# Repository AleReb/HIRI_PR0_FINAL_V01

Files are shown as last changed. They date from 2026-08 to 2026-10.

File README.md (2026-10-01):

# FirmwarePro (HIRI)

Firmware para estación de monitoreo técnico-científico basada en ESP32, con adquisición de sensores, GNSS, registro en SD, telemetría HTTP y gestor de archivos por WiFi AP.

## Estado

- Plataforma objetivo: **ESP32 Dev Module** (`esp32:esp32:esp32`)
- Versión de referencia documentada: **Pro V0.1.8**

## Funcionalidades principales

- Lectura de **PMS5003** (PM1/PM2.5/PM10 + T/H según modelo)
- Lectura de **SDS198** (PM100)
- Lectura opcional de **SHT31**
- GNSS por módem SIM7600 (posición, altitud, velocidad, satélites, HDOP)
- Registro en **CSV diario** en tarjeta SD
- Envío HTTP de mediciones a backend
- UI local con OLED + 2 botones
- Modo **WiFi SD** con web manager (upload/download/rename/delete)
- Captive portal DNS para mejor compatibilidad en Windows

## Carrusel de datos persistente

En **Opciones > Configuración > Carrusel**, BTN2 abre una pantalla de control
similar a RTC. Allí **BTN2 activa/desactiva** el carrusel y **BTN1 sale**.
El estado ON/OFF se guarda en flash y se conserva al apagar o reiniciar.
Por defecto está desactivado.

Desde Serial (115200 baud, nueva línea):

```text
set carousel on
set carousel off
config display
```

Los comandos `set` guardan automáticamente con el mismo `saveConfig()` que las
demás opciones. `config` muestra también el estado, `configsave` sigue disponible
y `configreset` restaura carrusel OFF. `help` incluye la opción y sus controles.

En las vistas de datos del inicio, rota cada **10 segundos**:
**PM2.5 > temperatura > humedad**. Usa las lecturas Plantower
actuales, conservando encabezado y controles. Los puntos inferiores indican
una de las tres páginas del carrusel. Los botones mantienen la navegación habitual.
Al navegar a Empezar/Detener muestreo u Opciones, muestra la opción elegida
durante 10 segundos; si no se selecciona, vuelve a PM2.5.
Se pausa dentro de submenús, confirmaciones, WiFi, modo Full y con la OLED apagada por
inactividad. La rotación no reinicia el plazo de apagado automático. Al volver
al inicio o navegar manualmente, espera otros 10 segundos antes de cambiar.

## Reinicio manual del equipo

**Configuración > Reiniciar** y el comando Serial `reboot` utilizan el mismo
reinicio. Primero muestran el aviso durante 750 ms, sin comenzar otra tarea
AT/HTTP. Se reinicia el ESP32 y el siguiente arranque **primero verifica AT**,
registro de datos y PDP. Con una sesion previa activa prueba una conexion TCP
al host de `API_BASE`, sin enviar mediciones. Si el modem responde, conserva
su encendido y recupera red/PDP si hace falta; un fallo TCP del servidor no
provoca apagado. Si no hay AT tras la espera y se trata de reinicio manual,
recuperacion automatica, panic o watchdog, solicita el ciclo del modem con
cuenta regresiva de 30 segundos. Conserva los 5 strikes.
Los mensajes `[BOOT]` y `[MODEM]` permiten seguir cada etapa por Serial.

El reinicio manual mantiene la configuración persistente, pero deja el muestreo
apagado. El reinicio automático de recuperación conserva su restauración de
muestreo. PWRKEY/CPOF solicitan el ciclo del módem; no cortan VBAT ni permiten
verificar el apagado físico sin una señal STATUS.

El LED pulsa azul durante la animacion y las esperas AT/red/recuperacion,
tambien dentro de TinyGSM, con la misma secuencia tras reinicio y encendido.
Respeta `set led off`. Al entrar al loop vuelve al color de PM2.5.
En un reset que conserva el modem se omite la descarga XTRA inicial para
no sumar otra espera de hasta 120 segundos. La prueba TCP confirma acceso
al servidor consultado; un fallo no distingue caida del servidor de falta
de ruta a internet.

## Configurar equipos y sensores de la API

En `HIRI_PR0_FINAL_V01.ino`, cambie solamente `DEVICE_ID_STR` para seleccionar
un equipo de `DEVICE_API_PROFILES`. La tabla permanece junto a `API_BASE`,
en el lugar de las listas originales, con todos los equipos visibles.
La URL utiliza los IDs de sensores, variables y valores del perfil elegido.
`"06"` y `"6"` seleccionan el mismo perfil; el identificador escrito se conserva
en pantalla, archivos y valor enviado del equipo.

Para agregar un equipo, copie una fila de la tabla y complete:

- ID del equipo.
- Lista de IDs de sensores asignados por el backend.
- Lista de variables: base, SHT31 o SDS198.
- Sensor extra: `EXTRA_NONE`, `EXTRA_SHT31` o `EXTRA_SDS198`.

El orden de las mediciones está comentado encima de la tabla. Las tres listas
(sensores, variables y valores) deben tener la misma cantidad de campos.
Si el ID no existe o las cantidades no coinciden, el firmware rechaza el
envío HTTP y deja un mensaje en Serial; los sensores y la pantalla continúan.
Los IDs del backend son explícitos: no se deducen del número de equipo.

Para un tipo de sensor nuevo, agregue su opción a `ExtraSensorApi`, su lista
de variables y los valores correspondientes en `buildMeasurementUrl()`.
La inicialización y lectura del hardware se agregan en `setup()`/`loop()`;
la tabla configura la telemetría y conserva los drivers actuales.

### Lista de dispositivos HIRI

Perfiles disponibles en `DEVICE_API_PROFILES`: **1–10 y 80–89**.
Los HIRI **82 y 83** ya estaban registrados y coinciden con los mapeos
proporcionados; se agregaron **84, 85, 86, 87, 88 y 89**. Cada uno utiliza
19 valores y el perfil `EXTRA_SHT31`. HIRI 86 tiene una sola entrada.

| HIRI / DEVICE_ID_STR | PMS, campos 1–5 | Módem/GPS, 6–10 | RTC, 11 | Batería, 12 | Equipo, 13–17 | SHT31, 18–19 |
|---|---|---|---|---|---|---|
| 82 | 939 | 940 | 941 | 942 | 943 | 944 |
| 83 | 945 | 946 | 947 | 948 | 949 | 950 |
| 84 | 951 | 952 | 953 | 954 | 955 | 956 |
| 85 | 957 | 958 | 959 | 960 | 961 | 962 |
| 86 | 963 | 964 | 965 | 966 | 967 | 968 |
| 87 | 969 | 970 | 971 | 972 | 973 | 974 |
| 88 | 975 | 976 | 977 | 978 | 979 | 980 |
| 89 | 981 | 982 | 983 | 984 | 985 | 986 |

Cada ID de la tabla se repite para todos los campos de su grupo. Por ejemplo,
HIRI 84 utiliza cinco veces 951 para PMS, cinco veces 952 para módem/GPS,
953 para RTC, 954 para batería, cinco veces 955 para equipo y dos veces 956
para SHT31. El firmware mantiene las listas completas y explícitas.

El orden de `idsVariables` es común a estos ocho equipos:

```text
3,6,7,8,9,11,12,15,45,46,3,4,11,12,42,43,44,3,6
```

| Posición | Grupo | ID variable | Valor enviado | Unidad |
|---|---|---|---|---|
| 1 | PMS | 3 | Temperatura | °C |
| 2 | PMS | 6 | Humedad | % |
| 3 | PMS | 7 | PM1.0 | µg/m³ |
| 4 | PMS | 8 | PM2.5 | µg/m³ |
| 5 | PMS | 9 | PM10 | µg/m³ |
| 6 | Módem/GPS | 11 | Latitud | ° |
| 7 | Módem/GPS | 12 | Longitud | ° |
| 8 | Módem/GPS | 15 | Intensidad de señal telefónica | Adimensional |
| 9 | Módem/GPS | 45 | Velocidad | km/h |
| 10 | Módem/GPS | 46 | Satélites | Entero |
| 11 | RTC | 3 | Temperatura interna | °C |
| 12 | Batería | 4 | Voltaje | V |
| 13 | Equipo | 11 | Latitud | ° |
| 14 | Equipo | 12 | Longitud | ° |
| 15 | Equipo | 42 | Identificador DEVICE_ID_STR | String |
| 16 | Equipo | 43 | Número de envíos | Numeral |
| 17 | Equipo | 44 | Registro SD activo | Bool (0/1) |
| 18 | SHT31 | 3 | Temperatura | °C |
| 19 | SHT31 | 6 | Humedad | % |

Para seleccionar uno, cambie solamente el identificador, por ejemplo:

```cpp
const char *DEVICE_ID_STR = "89";
```

Los textos descriptivos de `valores` proporcionados representan el significado
de cada campo. El firmware los sustituye por las lecturas actuales al construir
la URL de `insertarMedicion`, usando el endpoint definido en `API_BASE`.

## Arranque y recuperación sin conexión

Debajo de `VERSION`, en `HIRI_PR0_FINAL_V01.ino`, configure:

```cpp
const uint8_t CONNECTION_MAX_STRIKES = 5;
```

Antes de pulsar PWRKEY se consulta AT durante hasta 15 segundos, porque un
reinicio del ESP32 puede dejar el módem encendido. Si no responde, se aplica
el pulso de la placa y se permiten 5 strikes de 15 segundos cada uno.
PWRKEY se vuelve a pulsar solo cada 3 strikes sin respuesta, dejando unos
45 segundos entre pulsos. Esto conserva los reintentos del original y permite
completar el arranque de la UART. La etapa AT puede tardar unos 90 segundos.

El registro celular permite 5 intentos de hasta 60 segundos, como la espera
por intento del firmware antiguo. PDP agrega los tiempos internos de TinyGSM
(hasta 60 s de NETCLOSE y 75 s de NETOPEN, además de otros comandos).
Por eso el arranque sin red puede tardar varios minutos. Una vez agotados los
intentos, se pasa al modo normal para leer y mostrar datos. Sin AT se omiten
GNSS y HTTP; con AT pero sin internet, GNSS se inicia y se omite XTRA.

En el loop se consulta PDP cada minuto. Tras **30 minutos continuos sin PDP**,
se guardan contadores, archivo CSV y estados HTTP/SD, y se reinicia el ESP32.
Ese arranque comprueba primero AT y PDP; conserva un módem que responde.
Solo si AT no responde tras esperar solicita apagarlo/encenderlo y espera
30 segundos para completar el apagado. Se restaura el muestreo que
estaba activo; SD se restaura solamente si se monta correctamente. La marca de
recuperación es de un solo uso y solo se aplica a ese reinicio por software.

Recuperar PDP reinicia el contador de desconexión. Un error HTTP del servidor
no provoca reinicio si PDP sigue activo. Durante WiFi SD no se reinicia el
equipo: al salir se dispone de otros 30 minutos. El plazo se ajusta mediante
`NETWORK_REBOOT_AFTER_MS`, junto a la versión.

HTTP hace un intento de reconexión PDP por llamada y espera al menos 60 segundos
tras un fallo. El watchdog es de 180 segundos para permitir que TinyGSM termine;
la llamada PDP sigue siendo bloqueante y puede pausar la UI mientras espera.

La polaridad GPIO4 HIGH/LOW se conserva de la placa actual. PWRKEY es una
solicitud de encendido/apagado, no un corte de alimentación. Sin STATUS ni
control de VBAT no se puede verificar un apagado físico. Referencia de tiempos:
[SIMCom SIM7600 Hardware Design, sección 3.2](https://media.digikey.com/pdf/Data%20Sheets/SIMCom%20PDFs/SIM7600_Series_Hardware_Design.pdf).

## Documentación

- **Manual de Usuario:** `documentacion/MANUAL_USUARIO.md`
- **Manual Técnico:** `documentacion/MANUAL_TECNICO.md`
- **PCB, pinout y revisión de hardware:** [`PCB/README.md`](PCB/README.md)
- **Historial de cambios:** `documentacion/CAMBIOS.md`
- **Guía de desarrollo/versionado:** `documentacion/DEVELOPER_GUIDELINES.md`
- **Estructura de menú:** `documentacion/menu_structure.md`
- **Licencia:** `LICENSE`

## Test independiente de componentes

El repositorio incluye el sketch
[`test_componentes/test_componentes.ino`](test_componentes/test_componentes.ino),
diseñado para revisar el hardware básico antes de cargar el firmware completo.
Esta prueba funciona de manera independiente y no inicia el módem, GNSS, WiFi,
tarjeta SD, SDS198 ni los servicios de telemetría.

### Componentes revisados

| Componente | Conexión usada | Prueba realizada |
|---|---|---|
| OLED SSD1306 128×64 | I²C `0x3C`, SDA 21, SCL 22 | Detección I²C, patrón visual y pantalla de estado |
| RTC DS3231 | I²C `0x68` | Presencia, hora, temperatura interna y pérdida de alimentación |
| SHT41 | I²C `0x44` | Detección, número de serie, temperatura y humedad en pantalla dedicada |
| Plantower/PMS | 9600 baud, RX 5, TX 18 | Trama, checksum, PM1, PM2.5, PM10 y T/H cuando el modelo las incluye |
| NeoPixel RGB | GPIO 12 | Secuencia rojo, verde, azul, blanco y apagado |
| Botón 1 | GPIO 19, activo en HIGH | Estado, antirrebote y contador de pulsaciones |
| Botón 2 | GPIO 23, activo en HIGH | Estado, antirrebote y contador de pulsaciones |
| Batería | ADC GPIO 35 | Promedio filtrado y voltaje calibrado |

Los botones utilizan las resistencias pull-down externas de la placa. Por eso se
configuran como `INPUT`: sueltos se leen en LOW y pulsados en HIGH.

### Información mostrada

La OLED utiliza el mismo constructor SSD1306, fuente y rotación `U8G2_R2` del
firmware principal. Al arrancar muestra un patrón de pantalla y luego alterna
cada cinco segundos entre el resumen general y una pantalla dedicada al SHT41.
El resumen es similar al siguiente:

```text
TEST COMPONENTES HIRI
O:3C R:OK 12:34:56
PMS:1/25/10 5/12/18
PMS T/H:23.4C 45.2%
RGB:VERDE BAT:4.08V
B1:UP #0    B2:UP #0
```

- `PMS:ESPERANDO` indica que todavía no llegó una trama.
- `PMS:SIN DATOS/FAIL` indica ausencia de tramas válidas o pérdida de datos.
- `PMS T/H:NO DISP.` indica que el Plantower transmite partículas, pero su
  modelo no incluye temperatura y humedad válidas.
- `R:BAT!` indica que el RTC responde, pero registró una pérdida de alimentación
  y su hora podría ser incorrecta. El test nunca modifica la hora del RTC.
- `B1` y `B2` muestran `UP` al soltar, `DOWN` al pulsar y el total de
  pulsaciones válidas.

El monitor serie a **115200 baud** entrega además el escaneo I²C, cada trama
válida del Plantower, errores de checksum, hora y temperatura del RTC, cambios
del RGB, pulsaciones y voltaje de batería.

El encabezado cambia a `TEST: TODO OK*` cuando OLED, RTC, SHT41, Plantower,
batería y ambos botones superan las verificaciones automáticas. Para la batería se acepta
como rango diagnóstico de una celda conectada entre 2,50 V y 4,50 V. El
asterisco recuerda que el RGB debe comprobarse visualmente: el ESP32 puede
ordenar un color, pero no medir si el LED realmente emitió luz.

### Controles del test

- **BTN1:** avanza manualmente al siguiente color del NeoPixel.
- **BTN2:** activa o desactiva el recorrido automático de colores.

### Uso del test

1. Abra `test_componentes/test_componentes.ino` en Arduino IDE.
2. Seleccione **ESP32 Dev Module**.
3. Use las dependencias incluidas en [`libraries`](libraries/README.md).
4. Cargue el sketch y abra el monitor serie a **115200 baud**.
5. Revise el patrón OLED, los colores y los valores mostrados.
6. Pulse ambos botones al menos una vez y confirme que sus estados y contadores
   cambien correctamente.

Con Arduino CLI, la ruta de librerías debe indicarse explícitamente:

```powershell
arduino-cli compile --fqbn esp32:esp32:esp32 --libraries .\libraries .\test_componentes
```

## Compilación y carga (Arduino CLI)

Las dependencias externas están consolidadas en `libraries/`. Consulte
[`libraries/README.md`](libraries/README.md) para ver versiones y licencias.

### Compilar

```bash
arduino-cli compile --fqbn esp32:esp32:esp32 --libraries ./libraries .
```

### Subir a dispositivo (ejemplo COM5)

```bash
arduino-cli upload -p COM5 --fqbn esp32:esp32:esp32 FirmwarePro.ino
```

## Disclaimer de responsabilidad

Este proyecto se entrega **"tal cual"** (as-is), sin garantías explícitas ni implícitas de funcionamiento, disponibilidad o aptitud para un propósito específico.

El despliegue en terreno, la seguridad del sistema, la validación de datos y el cumplimiento normativo son responsabilidad del usuario/integrador.

Los autores y colaboradores no se responsabilizan por pérdidas de datos, daños directos o indirectos ni por uso fuera de contexto técnico seguro.

## Licencia de documentación

La documentación de este repositorio se publica bajo:

**Creative Commons Attribution-NonCommercial 4.0 International (CC BY-NC 4.0)**  
https://creativecommons.org/licenses/by-nc/4.0/

- ✅ Se permite compartir y adaptar con atribución.
- ❌ No se permite uso comercial sin autorización adicional.

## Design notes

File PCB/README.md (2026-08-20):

# Hardware PCB de HIRI Pro

Esta carpeta contiene la placa portadora (*carrier board*) correspondiente al
firmware principal [`HIRI_PR0_FINAL_V01.ino`](../HIRI_PR0_FINAL_V01.ino). El
diseño aloja el módulo ESP32/SIM7600 mediante dos hileras de 15 pines y distribuye
alimentación y señales hacia el sensor Plantower, pantalla, RTC, LED RGB y dos
botones.

> **Estado de la revisión (19-08-2026): no enviar todavía a fabricación.** El
> archivo de placa contiene cuatro conexiones sin rutear en `3V3`; además, deben
> resolverse las observaciones de compatibilidad con el firmware indicadas más
> abajo y ejecutar ERC/DRC en EAGLE.

## Archivos del diseño

| Archivo | Contenido |
|---|---|
| [`HiriPro/HirigrandeCHINA V2.1.sch`](HiriPro/HirigrandeCHINA%20V2.1.sch) | Esquemático eléctrico |
| [`HiriPro/HirigrandeCHINA V2.1.brd`](HiriPro/HirigrandeCHINA%20V2.1.brd) | Layout de la PCB |

Los dos archivos son XML de **Autodesk EAGLE 9.6.2**. El repositorio no incluye
Gerbers, archivos de perforado, *pick and place* ni BOM de fabricación; estos
deben exportarse únicamente después de cerrar la revisión eléctrica y el DRC.

## Bloques de hardware

- `JP1` y `JP2`: cabezales 1x15 del módulo ESP32/SIM7600.
- `XA1`: conector Molex 53048-0810 de ocho posiciones para Plantower/PMS.
- `STEPUP`: cabecera de tres pines para elevador `VBAT` a `5V`.
- `RTC`: conector JST-XH de cinco posiciones para DS3231.
- `SCREEN`: conector JST-SH para la pantalla OLED I²C.
- `I2C`: conector JST-SH de expansión I²C; permite conectar, por ejemplo, el
  SHT31 utilizado opcionalmente por el firmware.
- `RGB`: conector JST-SH para NeoPixel externo.
- `U$1` y `U$2`: pulsadores Cherry MX, con resistencias pull-down de 10 kΩ.
- `C1` a `C10`: posiciones SMC_D para condensadores polarizados. Sus valores no
  están definidos en el esquemático y deben completarse antes de generar la BOM.

La PCB es de dos capas: `Top` y `Bottom`. Las reglas guardadas especifican pista
mínima de 0,4 mm, perforación mínima de 0,35 mm y separación pista-pista de
0,3 mm. Estos valores describen el archivo, pero no sustituyen la comprobación
contra las capacidades del fabricante elegido.

## Pinout y relación con el firmware

### Señales principales del ESP32

| Función | GPIO efectivo | Red o conexión PCB | Definición en firmware | Revisión |
|---|---:|---|---|---|
| Módem RX | 26 | Pin del módulo en `JP1` | `MODEM_RX` | Coincide |
| Módem TX | 27 | Pin del módulo en `JP1` | `MODEM_TX` | Coincide |
| Módem PWRKEY | 4 | Pin del módulo en `JP1` | `MODEM_PWRKEY` | Coincide |
| Módem DTR | 32 | Pin del módulo en `JP1` | `MODEM_DTR` | Coincide |
| Módem FLIGHT | 25 | Pin del módulo en `JP1` | `MODEM_FLIGHT` | Coincide |
| PMS: recepción del ESP32 | 5 | `JP2.7` (`RX2`) ↔ `XA1.5` | Uso efectivo de `SoftwareSerial` | Coincide, pero los nombres de macros inducen a error |
| PMS: transmisión del ESP32 | 18 | `JP2.6` (`TX2`) ↔ `XA1.4` | Uso efectivo de `SoftwareSerial` | Coincide, pero los nombres de macros inducen a error |
| I²C SDA | 21 | `JP2.10`, `RTC.4`, `SCREEN.1`, `I2C.1` | `Wire` por defecto | Coincide |
| I²C SCL | 22 | `JP2.11`, `RTC.3`, `SCREEN.2`, `I2C.2` | `Wire` por defecto | Coincide |
| NeoPixel | 12 | `JP1.14` (`RGB`) ↔ `RGB.1` | `NEOPIX_PIN` | Coincide |
| Botón 1 | 19 | `JP2.9` (`BOT1`) | `BUTTON_PIN_1` | GPIO coincide; lógica eléctrica por corregir |
| Botón 2 | 23 | `JP2.8` (`BOT2`) | `BUTTON_PIN_2` | GPIO coincide; lógica eléctrica por corregir |
| SD SCLK | 14 | Pin del módulo en `JP1` | `SD_SCLK` | Coincide |
| SD MISO | 2 | Pin del módulo en `JP1` | `SD_MISO` | Coincide |
| SD MOSI | 15 | Pin del módulo en `JP1` | `SD_MOSI` | Coincide |
| SD CS | 13 | Pin del módulo en `JP1` | `SD_CS` | Coincide |
| Medición de batería | 35 | Sensado propio del módulo | `BAT_PIN` | No está implementado como una red separada en esta carrier |
| SDS198 RX | 39 | Conexión externa al módulo | `Serial2.begin(..., 39, -1)` | No existe conector dedicado en esta PCB |

En [`config.h`](../config.h), las macros del PMS se llaman `pms_RX=18` y
`pms_TX=5`, pero el objeto se construye en orden invertido:
`SoftwareSerial pms(pms_TX, pms_RX)`. Por eso la configuración efectiva del
ESP32 es **RX=GPIO5 y TX=GPIO18**, que es la que debe usarse al comprobar la
placa. Conviene renombrar esas macros en una futura revisión para eliminar la
ambigüedad.

`POWER_PIN` está definido como GPIO33, pero su uso se encuentra comentado en el
firmware principal. La red GPIO33 de la placa no controla actualmente una carga
desde el programa.

### Conectores periféricos

Las referencias siguientes usan el número de pad guardado en EAGLE. Antes de
armar cables, confirme también la orientación del conector y la marca de pin 1
en la vista de placa.

| Conector | Pad | Señal |
|---|---:|---|
| `XA1` Plantower | 8 | `5V`, salida del step-up |
|  | 7 | `GND` |
|  | 6 | `SET`, sin conexión al ESP32 |
|  | 5 | `RX2`; datos del sensor hacia RX del ESP32 (GPIO5) |
|  | 4 | `TX2`; datos del ESP32 (GPIO18) hacia RX del sensor |
|  | 1–3 | Sin conexión |
| `RTC` | 1 | `GND` |
|  | 2 | Sin conexión |
|  | 3 | `SCL` |
|  | 4 | `SDA` |
|  | 5 | `3V3` |
| `SCREEN` | 1 | `SDA` |
|  | 2 | `SCL` |
|  | 3 | `GND` |
|  | 4 | `VBAT` |
|  | 5–6 | Blindaje a `GND` |
| `I2C` | 1 | `SDA` |
|  | 2 | `SCL` |
|  | 3 | `GND` |
|  | 4 | `VBAT` |
|  | 5–6 | Blindaje a `GND` |
| `RGB` | 1 | Datos, GPIO12 |
|  | 2 | `GND` |
|  | 3 | `VBAT` |
|  | S1–S2 | Blindaje a `GND` |
| `STEPUP` | 1 | Entrada `VBAT` |
|  | 2 | `GND` |
|  | 3 | Salida `5V` hacia `XA1.8` |

**Atención:** `SCREEN`, `I2C` y `RGB` reciben `VBAT`, no `3V3` regulados. Antes
de conectar un módulo, compruebe su rango de alimentación y el voltaje máximo de
la batería. Las líneas lógicas del ESP32 siguen siendo de 3,3 V.

## Hallazgos pendientes

### 1. Cuatro conexiones `3V3` sin rutear

El `.brd` conserva cuatro segmentos en la capa EAGLE `19 Unrouted`, todos en la
red `3V3`:

| Desde (mm) | Hasta (mm) |
|---|---|
| `(48.625, 19.625)` | `(48.625, 19.6893)` |
| `(48.750, 10.175)` | `(48.750, 10.2500)` |
| `(34.450, 14.900)` | `(34.425, 14.9500)` |
| `(34.600, 19.625)` | `(34.500, 19.5250)` |

Aunque son segmentos muy cortos, EAGLE todavía los considera *airwires*. Se
deben rutear o resolver mediante el plano de cobre y luego ejecutar `RATSNEST`
hasta obtener **0 unrouted**.

### 2. Lógica de botones incompatible

En el esquemático, cada pulsador conecta su señal a `3V3` y tiene una resistencia
externa de 10 kΩ a `GND`: queda suelto en LOW y pulsado en HIGH. Sin embargo, el
firmware principal configura ambos GPIO como `INPUT_PULLUP` y atiende el flanco
`FALLING`. Esto puede registrar la liberación en vez de la pulsación y enfrenta
el pull-up interno con el pull-down externo.

Debe elegirse y probarse una solución antes de liberar hardware/firmware:

- conservar la PCB y usar entradas normales o pull-down, con interrupción
  `RISING`; o
- conservar la lógica activa en LOW del firmware y modificar el circuito para
  que el pulsador conecte a GND con pull-up.

El sketch [`test_componentes/test_componentes.ino`](../test_componentes/test_componentes.ino)
ya prueba la primera topología: entradas activas en HIGH con los pull-down de la
placa.

### 3. BOM incompleta

`C1` a `C10` usan encapsulado polarizado SMC_D, pero no tienen capacitancia ni
tensión nominal asignadas. También debe registrarse el modelo exacto del módulo
step-up. No sustituya componentes ni genere una orden de montaje hasta definir
estos datos y verificar polaridades.

### 4. Periféricos que no tienen conector dedicado

El firmware lee un SDS198 por GPIO39 y puede leer un SHT31 en `0x44`. La carrier
no ofrece un conector rotulado para SDS198; el SHT31 puede compartir `I2C`, pero
el conector lo alimenta desde `VBAT`. Estas conexiones deben quedar definidas en
el mazo de cables y en la matriz de versión del equipo.

## Procedimiento de validación recomendado

1. Abrir juntos el `.sch` y el `.brd` en EAGLE 9.6.2 o una versión compatible.
2. Completar valores y números de parte de la BOM.
3. Resolver las cuatro conexiones `3V3` y confirmar `RATSNEST: 0 unrouted`.
4. Ejecutar ERC sobre el esquemático y DRC sobre la placa usando las reglas del
   fabricante; documentar todas las excepciones.
5. Resolver la topología de los botones y sincronizarla con el firmware.
6. Verificar orientación y continuidad de cada conector con un multímetro, sin
   insertar todavía el ESP32 ni los sensores.
7. Alimentar con fuente limitada en corriente y comprobar `VBAT`, `3V3` y la
   salida `5V` del step-up.
8. Insertar el módulo y ejecutar el
   [`test_componentes`](../test_componentes/README.md) antes del firmware completo.
9. Validar OLED, RTC, PMS, RGB, botones y batería; después probar SD, módem,
   GNSS, SDS198 y telemetría con el firmware principal.
10. Solo entonces exportar Gerbers/Excellon y revisar visualmente cada capa,
    máscara, serigrafía, contorno y perforación.

## Trazabilidad

El nombre del diseño indica revisión de hardware **V2.1**. La versión del
firmware se mantiene por separado en la constante `VERSION`. Para cada lote se
recomienda registrar como mínimo: revisión de PCB, commit del repositorio,
versión de firmware, BOM aprobada, fabricante y fecha de montaje.

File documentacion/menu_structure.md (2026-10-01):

# Estructura del Menú FirmwarePro (Actualizada)

Referencia: `ui.ino` (estado actual de navegación y acciones).

## Controles

- **BTN1 (PIN 19):** navegar/ciclar opciones (`menuIndex + 1`).
- **BTN2 (PIN 23):** seleccionar / entrar / confirmar.

> Nota: la lógica por **hold** fue retirada. El flujo es por clics.

---

## Estados especiales de UI

- `DISP_NORMAL` → navegación normal.
- `DISP_MESSAGE` → mensaje temporal no bloqueante.
- `DISP_PROMPT` → confirmación de iniciar/detener muestreo.
- `DISP_NETWORK` → pantalla de red.
- `DISP_CAROUSEL` → control persistente del carrusel (BTN2 ON/OFF, BTN1 salir).
- `DISP_RTC` → pantalla RTC (con sincronización por BTN2).
- `DISP_STORAGE` → pantalla de archivo/tamaño.
- `DISP_GPS` → pantalla de estado GPS.
- **Modo FULL** (`uiFullMode=true`) → vista completa de telemetría.
- **Modo WiFi activo** (`wifiModeActive=true`) → pantalla dedicada WiFi y salida por BTN2.

---

## Estructura jerárquica actual

## 1) Menú Principal (Depth 0)

| Índice | Texto | Acción |
|---|---|---|
| 0 | PM2.5 | Vista de valor grande PM2.5 |
| 1 | TEMPERATURA | Vista de valor grande temperatura |
| 2 | HUMEDAD | Vista de valor grande humedad |
| 3 | EMPEZAR/DETENER MUESTREO | Abre `DISP_PROMPT` para confirmar |
| 4 | OPCIONES | Entra a submenú Depth 1 |

---

## 2) Submenú Opciones (Depth 1)

| Índice | Texto | Acción |
|---|---|---|
| 0 | MENSAJES | Entra Depth 2 |
| 1 | CONFIGURACION | Entra Depth 3 |
| 2 | INFORMACION | Entra Depth 4 |
| 3 | VOLVER | Regresa a Depth 0 |

---

## 3) Submenú Mensajes (Depth 2)

| Índice | Texto | Acción |
|---|---|---|
| 0 | CAMION | Set `currentNote="Camion"` (one-shot CSV) |
| 1 | HUMO | Set `currentNote="Humo"` (one-shot CSV) |
| 2 | CONSTRUCCION | Set `currentNote="Construccion"` (one-shot CSV) |
| 3 | OTROS | Set `currentNote="Otros"` (one-shot CSV) |
| 4 | VOLVER | Regresa a Depth 1 |

---

## 4) Submenú Configuración (Depth 3)

| Índice | Texto | Acción |
|---|---|---|
| 0 | RTC | Abre pantalla `DISP_RTC` |
| 1 | CARRUSEL: ON/OFF | Abre `DISP_CAROUSEL`; BTN2 alterna y guarda |
| 2 | REINICIAR | Ejecuta `handleRestart()` |
| 3 | VOLVER | Regresa a Depth 1 |

---

## 5) Submenú Información (Depth 4)

| Índice | Texto | Acción |
|---|---|---|
| 0 | VERSION | Muestra versión (`DISP_MESSAGE`) |
| 1 | REDES | Abre `DISP_NETWORK` |
| 2 | GPS | Abre `DISP_GPS` |
| 3 | GUARDADO | Abre `DISP_STORAGE` |
| 4 | WIFI SD (ON/OFF) | Inicia/detiene AP WiFi |
| 5 | MODO FULL | Activa vista completa de telemetría |
| 6 | VOLVER | Regresa a Depth 1 |

---

## Reglas de interacción relevantes

- En `DISP_PROMPT`:
  - BTN1: cancelar.
  - BTN2: confirmar start/stop.
- En `DISP_RTC`:
  - BTN2: sincroniza RTC desde módem.
- En Modo FULL:
  - BTN1: toggle rápido muestreo.
  - BTN2: salir a menú normal.
- En modo WiFi activo:
  - BTN2: salir y apagar WiFi.

---

## Observación para desarrollo

Cada modificación de menú debe sincronizarse con:
1. `ui.ino`
2. `MANUAL_USUARIO.md`
3. `menu_structure.md`
4. `CAMBIOS.md` (si es cambio funcional)

## Carrusel del inicio

Al habilitarlo rota PM2.5, temperatura y humedad cada 10 segundos.
Se pausa fuera de las vistas de datos normales. La navegación manual reinicia
la espera, y la selección ON/OFF se conserva en Preferences (`config/carousel`).
Serial: `set carousel on/off`; consulta: `config display`; ayuda: `help`.

En Empezar/Detener muestreo y Opciones del inicio, el carrusel vuelve a PM2.5
tras 10 segundos sin seleccionar. Dentro de submenús o confirmaciones se pausa.
Reiniciar reinicia ESP32; el siguiente arranque verifica AT/PDP antes de decidir
si solicita un ciclo SIM7600. Un modem que responde permanece encendido.

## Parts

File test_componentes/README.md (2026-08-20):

# Test independiente de componentes HIRI

Este sketch prueba solamente los componentes básicos armados por separado:

- OLED SSD1306 128×64 en `0x3C`, con la misma configuración y rotación R2 del
  firmware principal
- RTC DS3231, I²C `0x68`
- SHT41, I²C `0x44`, temperatura y humedad con `Adafruit_SHT4x`
- NeoPixel RGB en GPIO 12
- botón 1 en GPIO 19
- botón 2 en GPIO 23
- voltaje de batería en ADC GPIO 35
- Plantower/PMS a 9600 baud, con la misma configuración del firmware principal
  (`SoftwareSerial RX=GPIO5, TX=GPIO18`)

No inicia el módem, GNSS, tarjeta SD, WiFi ni sensores de partículas.

## Uso

1. Abra `test_componentes/test_componentes.ino` en Arduino IDE.
2. Seleccione **ESP32 Dev Module**.
3. Instale las librerías **U8g2**, **RTClib**, **Adafruit NeoPixel**,
   **Adafruit SHT4x**, **Adafruit BusIO** y **Adafruit Unified Sensor** si faltan.
4. Compile, cargue el sketch y abra el monitor serie a **115200 baud**.
5. Compruebe que el OLED muestre el resumen y que el RGB recorra rojo, verde,
   azul, blanco y apagado.
6. Pulse BTN1: debe incrementar su contador y cambiar manualmente el color.
7. Pulse BTN2: debe incrementar su contador y activar/desactivar el ciclo RGB.

La OLED alterna automáticamente cada cinco segundos entre el resumen general y
una pantalla dedicada al SHT41. Esta segunda pantalla muestra temperatura,
humedad y número de serie; si el dispositivo no responde en `0x44`, muestra
`NO ENCONTRADO`. El sensor se lee cada dos segundos en alta precisión y con el
calentador desactivado.

La línea `PMS` muestra `ESPERANDO`, `OK` con PM1/PM2.5/PM10, o
`SIN DATOS/FAIL`. El encabezado cambia a `TEST: TODO OK*` cuando OLED, RTC,
SHT41, Plantower, batería y los dos botones respondieron, y el RTC no informa
pérdida de energía. `RTC:BAT!` significa que el DS3231 responde, pero perdió alimentación y
su hora podría ser incorrecta. El asterisco recuerda que el RGB debe comprobarse
visualmente: el microcontrolador puede enviarle colores, pero no confirmar que
el LED emitió luz.

La pantalla también muestra `BAT:x.xxV`. La lectura utiliza la misma fórmula,
promedio y calibración del firmware principal. Para el resultado general se
considera razonable un valor entre 2,50 V y 4,50 V; fuera de ese rango, el monitor
serie indica `REVISAR`.

La línea siguiente del PMS muestra también temperatura y humedad cuando el
modelo Plantower incluye esos campos. Si el sensor transmite partículas pero no
incluye T/H, aparece `PMS T/H:NO DISP.`.

El escáner I²C informa todas las direcciones encontradas. Un RTC con
`lostPower` sigue siendo detectado, pero muestra una advertencia y el test no
modifica su hora.

El monitor serie identifica `0x44` como el SHT41 esperado y entrega una lectura
con el formato `[SHT41] T=... C | HR=... %`. Una lectura ausente, fuera de rango
o con error impide que el encabezado cambie a `TEST: TODO OK*`.

Al arrancar, la OLED debe encender todos sus píxeles durante medio segundo y
luego mostrar `OLED ENCONTRADA`. Se usa el constructor SSD1306 y la rotación
`U8G2_R2` del firmware base para mantener la alineación de la pantalla original.

Los botones se leen como activos en HIGH usando las resistencias pull-down que
ya existen en la placa: sueltos muestran `UP` y pulsados muestran `DOWN`.

## Compilación con Arduino CLI

```powershell
arduino-cli compile --fqbn esp32:esp32:esp32 --libraries .\libraries .\test_componentes
```

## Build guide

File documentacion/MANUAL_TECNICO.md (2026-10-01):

# FirmwarePro — Manual Técnico

Versión de referencia: **Pro V0.0.35**  
Objetivo: documentación técnica para operación, mantenimiento e integración de producto científico-técnico.

---

## 1) Arquitectura general

Firmware modular en archivos `.ino`:

- `FirmwarePro.ino` → núcleo (setup/loop, estados globales, orquestación)
- `config.h` / `config.ino` → estructura y persistencia de configuración
- `gps.ino` → GNSS (NMEA parsing, watchdog, diagnósticos, XTRA)
- `pms.ino` → PMS5003 + SDS198 + LED PM2.5
- `sd_card.ino` → gestión CSV, failed_tx, headers
- `http.ino` → ciclo HTTP por AT (SIM7600)
- `wifi.ino` → AP + WebServer + DNSServer (captive portal)
- `ui.ino` → menú OLED + botones + pantallas de estado
- `serial_commands.ino` → CLI serial completa
- `rtc.ino` → sincronización RTC y hora de módem
- `helpers.ino` → utilidades, logging y helpers de visualización

---

## 2) Hardware y pines

Definidos en `config.h`:

- SIM7600: TX27, RX26, PWRKEY4, DTR32, FLIGHT25
- PMS5003: RX18, TX5 (SoftwareSerial)
- Batería: ADC35
- Power control: 33
- NeoPixel: 12
- Botones: BTN1=19, BTN2=23
- SD (HSPI): SCLK14, MISO2, MOSI15, CS13

---

## 3) Máquina de estados operativa

Estados funcionales relevantes:

- `streaming` → habilita transmisión HTTP periódica
- `loggingEnabled` → habilita guardado SD periódico
- `wifiModeActive` → habilita modo AP/Web
- `displayState` (`DISP_*`) → subestados de UI

Bucle principal (`loop`):

1. `esp_task_wdt_reset()`
2. Atención de botones (`handleButtonLogic`)
3. Si `wifiModeActive`:
   - `dnsServer.processNextRequest()`
   - `server.handleClient()`
   - refresh de display
   - `return` (prioriza transferencia)
4. Si no hay WiFi activo:
   - GNSS watchdog/diag/debug
   - sensores PMS/SDS198
   - refresh pantalla
   - scheduler SD (`sdSavePeriod`) y HTTP (`httpSendPeriod`)
   - comandos seriales

---

## 4) Subsistema GNSS

Funciones clave (`gps.ino`):

- `gnssBringUp()` → encendido/config GNSS, NMEA 1Hz
- `setGnssAllWithFallback()` → set de constelación con fallback
- `gnssWatchdog()` → hot/warm restart si no hay fix
- `parseNMEA()` + `parseGGA/RMC/VTG/GSA/GSV`
- `gnssDiagTick()` → diagnósticos periódicos
- `gnssDebugPollAsync()` → consultas AT no bloqueantes
- XTRA:
  - `detectAndEnableXtra()`
  - `downloadXtraOnce()`
  - `downloadXtraIfDue()`

Modos GNSS soportados:
- 1 (GPS)
- 3 (GPS+GLONASS)
- 5 (GPS+BEIDOU)
- 7 (GPS+GLONASS+BEIDOU)
- 15 (ALL)

---

## 5) Subsistema SD y trazabilidad

`sd_card.ino`:

- `generateCSVFileName()` → archivo diario por ID
- `writeCSVHeader()` → cabecera controlada
- `saveCSVData()` → registro de muestra + nota one-shot
- `saveFailedTransmission()` → cola forense de fallas HTTP
- `writeErrorLogHeader()` → log estructurado

Formato CSV principal con 23 campos, incluyendo:
- telemetría ambiental
- telemetría GNSS
- salud de red
- estado XTRA
- motivo de reinicio
- `notas`

---

## 6) Subsistema HTTP/Red celular

`http.ino` implementa ciclo robusto por AT:

1. `ensurePdpAndNet()` (PDP + NETOPEN con backoff)
2. `HTTPINIT`
3. `HTTPPARA CID`
4. `HTTPPARA URL`
5. `HTTPACTION=0` (GET)
6. parseo de `+HTTPACTION:`
7. `HTTPREAD` (opcional)
8. `HTTPTERM`

Mecanismos de robustez:
- Backoff en reconexión PDP
- Timeout configurable (`config.httpTimeout`)
- watchdog feed durante espera
- logging estructurado de errores

---

## 7) Modo WiFi AP + File Manager

`wifi.ino`:

- AP local (`WiFi.softAP`)
- IP fija típica 192.168.4.1
- `DNSServer` en puerto 53 (captive portal)
- rutas HTTP:
  - `/`
  - `/download`
  - `/delete`
  - `/rename`
  - `/upload`
  - `/delete_all`
  - `/ip`
  - `/ssid`

Controles:
- saneamiento de nombres de archivo
- validación de SD disponible
- límite de listado

---

## 8) UI y experiencia operativa

`ui.ino`:

- Navegación por 2 botones
- confirmaciones para start/stop
- pantallas diagnósticas: red/RTC/GPS/almacenamiento
- modo full de visualización
- mensajes no bloqueantes (`DISP_MESSAGE`)
- flujo de notas one-shot desde menú Mensajes

---

## 9) Configuración persistente (Preferences)

Namespace `config`:
- `sdAuto`, `sdSavePer`
- `httpPer`, `httpTO`
- `oledOff`, `oledTO`
- `ledEn`, `ledBr`
- `autoStart`, `autoGPS`, `autoGPSTO`
- `gnssMode`

Namespace `system`:
- contadores (`sendCnt`, `sdCnt`)
- `csvFile`
- `streaming`

Namespace `rtc`:
- `syncCnt`

---

## 10) Serial CLI — referencia completa

Implementación en `serial_commands.ino` (entrada `\n`, case-insensitive).

## Ayuda
- `help`, `?`

## RTC/tiempo
- `rtc`

## Contadores/estadística
- `counters`
- `resetcnt`
- `stats`

## SD
- `sdinfo`
- `sdlist`
- `sdnew`
- `sdclear`
- `sdclear confirm`

## Red/modem
- `netinfo`
- `csq`

## Sistema
- `sysinfo`
- `mem`
- `reboot`

## Streaming
- `start`
- `stop`

## Config
- `config`
- `config sd`
- `config http`
- `config display`
- `config power`
- `set sdauto on|off`
- `set sdsave 3|60|600|1200`
- `set httpsend 3|60|600|1200`
- `set httptimeout <5..30>`
- `set carousel on|off` (Preferences: `config/carousel`, bool, default false)
- `set oledoff on|off`
- `set oledtime 60|120|180`
- `set led on|off`
- `set ledbright 10|25|50|100`
- `set autostart on|off`
- `set autowaitgps on|off`
- `set autogpsto <60..900>`
- `set gnssmode 1|3|5|7|15`
- `configreset`
- `configsave`

---

## 11) Procedimientos de validación (QA)

## 11.1 Build
- `arduino-cli compile --fqbn esp32:esp32:esp32 FirmwarePro.ino`

## 11.2 Flash
- `arduino-cli upload -p COMx --fqbn esp32:esp32:esp32 FirmwarePro.ino`

## 11.3 Smoke test
1. Boot sin errores en serial
2. SD montada y CSV creado
3. GNSS entrega NMEA/fix
4. HTTP responde 2xx
5. WiFi AP visible y web accesible en `192.168.4.1`
6. Operaciones CRUD de archivos en SD

---

## 12) Riesgos y mejoras sugeridas

- Password AP por defecto fija (endurecer para despliegue)
- Añadir autenticación HTTP para gestión de SD
- Añadir endpoint de salud (`/health`) con métricas internas
- Añadir test de regresión de comandos seriales
- Ajustar política exacta de GNSS durante WiFi exclusivo según consumo/latencia

---

## Apéndice A — Mensajes y logs clave

Prefijos frecuentes:
- `[BOOT]`, `[READY]`
- `[GNSS]`, `[GNSSDIAG]`, `[GSA]`, `[GSV]`
- `[HTTP]`, `[NET]`
- `[SD]`, `[FAILED_TX]`
- `[CONFIG]`, `[SYSTEM]`

---

## Apéndice B — Estructura de archivos SD

- `hiripro<ID>_DD_MM_YYYY.csv`
- `errors_h<ID>.csv`
- `failed_h<ID>.csv`

---

## Apéndice C — Integración de producto

Para empaquetado comercial/científico:

- Definir versión de firmware bloqueada por release
- Mantener matriz HW (sensores/módem compatibles)
- Establecer protocolo de calibración y mantenimiento
- Registrar trazabilidad de lote/dispositivo vía `DEVICE_ID_STR`
- Publicar este manual junto a procedimiento de QA de fábrica

---

## Apéndice D — Disclaimer de responsabilidad

Este firmware y este documento técnico se entregan **"as-is"** (tal cual), sin garantía de funcionamiento ininterrumpido ni adecuación a un caso de uso específico.  
La validación metrológica, seguridad eléctrica, cumplimiento regulatorio y operación final son responsabilidad del integrador/desplegador.  
Los autores no asumen responsabilidad por daños, pérdidas de datos o consecuencias derivadas del uso del sistema.

---

## Apéndice E — Licencia de documentación

Este manual se distribuye bajo:

**Creative Commons Attribution-NonCommercial 4.0 International (CC BY-NC 4.0)**  
https://creativecommons.org/licenses/by-nc/4.0/

Permisos principales:
- Compartir y adaptar con atribución.
- Uso no comercial.

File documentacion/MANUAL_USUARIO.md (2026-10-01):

# FirmwarePro — Manual de Usuario

Versión de referencia: **Pro V0.0.35**  
Plataforma: **ESP32 Dev Module (esp32:esp32:esp32)**

---

## 1) Propósito del equipo

FirmwarePro es un firmware para monitoreo ambiental y telemetría técnica que integra:

- Sensor de material particulado **PMS5003** (PM1/PM2.5/PM10 + T/H del módulo ST cuando aplica)
- Sensor **SDS198** (PM100)
- Sensor **SHT31** (temperatura/humedad, opcional)
- **GNSS** por módem SIM7600 (posición, altitud, velocidad, satélites, HDOP)
- Registro en **tarjeta SD** (CSV)
- Envío HTTP a backend remoto
- Interfaz local por **OLED + 2 botones**
- Modo **WiFi AP** para gestión de archivos en SD desde celular/PC

---

## 2) Arranque rápido

1. Energiza el equipo.
2. Espera animación de inicio y estado de módem/red.
3. En pantalla principal usa:
   - **BTN1**: navegar
   - **BTN2**: seleccionar/confirmar
4. Para empezar muestreo/transmisión:
   - Menú principal → **EMPEZAR MUESTREO** → confirmar con BTN2.

---

## 3) Navegación por pantalla (OLED)

## Menú principal
- PM2.5
- Temperatura
- Humedad
- Empezar/Detener muestreo
- Opciones

## Opciones
- Mensajes
- Configuración
- Información
- Volver

## Mensajes (nota one-shot al CSV)
- Camion
- Humo
- Construccion
- Otros
- Volver

> La nota seleccionada se escribe en la próxima fila CSV (columna `notas`) y luego se limpia automáticamente.

## Configuración
- RTC
- Carrusel ON/OFF: BTN2 entra y alterna; BTN1 sale. Se guarda automáticamente.
- Reiniciar
- Volver

## Información
- Versión
- Redes
- GPS
- Guardado (archivo actual y tamaño)
- WIFI SD (ON/OFF)
- Modo Full
- Volver

---

## 4) Modo WiFi SD (transferencia de archivos)

Al activar **WIFI SD (ON/OFF)**:

- El equipo levanta un AP WiFi con:
  - SSID: `HIRIPRO_<ID>` (ejemplo `HIRIPRO_1`)
  - Password: `12345678`
  - IP típica: `192.168.4.1`
- Se habilita servidor web para:
  - Ver archivos SD
  - Descargar
  - Subir
  - Renombrar
  - Borrar
  - Borrar todo

### Prioridad transferencia
En modo WiFi, el firmware prioriza atención de DNS/Web para mejorar estabilidad de transferencia.

### Compatibilidad Windows
Se incluye **DNS tipo captive portal** para mejorar detección en Windows y facilitar apertura del gestor web.

### Salida
Desde la UI, al salir del modo WiFi se apaga el AP y el equipo vuelve al ciclo normal.

---

## 5) Indicadores de operación

- Header OLED:
  - Hora
  - Estado de transmisión/SD (actividad y último estado)
  - Satélites/fix
  - Señal de red (CSQ)
  - Batería
- LED RGB (NeoPixel): nivel PM2.5 por gradiente de color.

---

## 6) Datos registrados en SD

Archivo diario por dispositivo:

`/hiripro<ID>_DD_MM_YYYY.csv`

Cabecera CSV:

`ts_ms,time,gpsDate,lat,lon,alt,spd_kmh,pm1,pm25,pm10,pmsTempC,pmsHum,rtcTempC,batV,csq,sats,hdop,xtra_ok,sht31TempC,sht31Hum,resetReason,pm100,notas`

Además:
- Log de errores: `/errors_h<ID>.csv`
- Transmisiones fallidas: `/failed_h<ID>.csv`

---

## 7) Uso recomendado en terreno

1. Verifica batería y CSQ antes de campaña.
2. Espera fix GNSS estable (satélites/HDOP razonable).
3. Inicia muestreo.
4. Usa notas (Camion/Humo/Construccion/Otros) para eventos de contexto.
5. Al finalizar, usa WiFi SD para respaldo rápido de CSV.

---

## 8) Solución de problemas (usuario)

### No aparece la web en Windows
- Confirmar conexión al SSID HIRIPRO.
- Abrir manualmente `http://192.168.4.1`.
- Desconectar/reconectar WiFi del PC.

### No guarda en SD
- Revisar que la SD esté bien insertada.
- Verificar en menú/serial estado SD.

### No transmite HTTP
- Revisar CSQ y operador.
- Confirmar cobertura celular y APN.

### GPS sin fix
- Dar más tiempo al GNSS al inicio.
- Revisar antena y vista al cielo.

---

## 9) Apéndice A — Comandos seriales (usuario avanzado)

Baudrate: **115200**, fin de línea `\n`.

Comandos principales:

- `help` / `?`
- `rtc`
- `counters`, `resetcnt`, `stats`
- `sdinfo`, `sdlist`, `sdnew`, `sdclear`, `sdclear confirm`
- `netinfo`, `csq`
- `sysinfo`, `mem`, `reboot`
- `start`, `stop`
- `config`, `config sd/http/display/power`
- `set sdauto on/off`
- `set sdsave 3|60|600|1200`
- `set httpsend 3|60|600|1200`
- `set httptimeout <5..30>`
- `set carousel on/off` (guardado automático; rota PM2.5/T/H cada 10 s)
- `set oledoff on/off`
- `set oledtime 60|120|180`
- `set led on/off`
- `set ledbright 10|25|50|100`
- `set autostart on/off`
- `set autowaitgps on/off`
- `set autogpsto <60..900>`
- `set gnssmode 1|3|5|7|15`
- `configreset`, `configsave`

---

## 10) Apéndice B — Seguridad operativa

- La password AP por defecto es conocida (`12345678`), usar en entorno controlado.
- Evitar exposición pública del AP.
- Respaldar SD periódicamente.

---

## 11) Disclaimer de responsabilidad

Este firmware y su documentación se entregan **"tal cual"**, sin garantías explícitas ni implícitas de desempeño, disponibilidad o aptitud para un propósito particular.  
El uso en terreno, decisiones operativas y cumplimiento normativo son responsabilidad del usuario/institución que lo despliega.  
El autor y colaboradores no se responsabilizan por pérdidas de datos, daños directos o indirectos, ni por usos fuera de contexto técnico seguro.

---

## 12) Licencia

Este manual se publica bajo licencia:

**Creative Commons Attribution-NonCommercial 4.0 International (CC BY-NC 4.0)**  
https://creativecommons.org/licenses/by-nc/4.0/

En resumen:
- ✅ Puedes compartir y adaptar con atribución.
- ❌ No se permite uso comercial sin autorización adicional.

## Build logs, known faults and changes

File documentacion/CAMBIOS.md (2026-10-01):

# Registro de Cambios - FirmwarePro

## [V0.1.8] - 2026-10-01
### Perfiles HIRI 84 a 89 y lista de dispositivos en README
- Se agregan equipos 84, 85, 86, 87, 88 y 89 a DEVICE_API_PROFILES, usando
  exactamente los IDs proporcionados y el perfil SHT31 de 19 valores.
- Se verifican equipos existentes 82 y 83; 86 se registra una sola vez.
- README incluye dispositivos disponibles, mapeos 82-89 y orden/unidades de
  los 19 campos de valores e IDs de variables.
- Se conserva DEVICE_ID_STR actual, endpoint API_BASE, 5 strikes y carrusel 10 s.
- Validacion: 20 perfiles unicos; HIRI 82-89 con 19 campos alineados y mapeos
  coincidentes con README. Compilacion ESP32 correcta (78% flash, 16% RAM).
- No se realizan solicitudes al endpoint de insercion para verificar mapeos.

## [V0.1.7] - 2026-10-01
### Comprobar modem antes de recuperarlo y pulso LED durante el arranque
- AT antes de CPOF/PWRKEY, tambien en reset manual, recuperacion y watchdog/panic.
- Consulta attach/PDP y prueba TCP al host de API_BASE sin enviar mediciones.
- Si AT responde, conservar modem; recuperar red/PDP sin apagarlo. Un fallo TCP
  del servidor no fuerza ciclo. Solo falta de AT permite ciclo en recuperacion.
- Pulso azul comun a encendido/reset, animacion y esperas TinyGSM mediante hook
  TINY_GSM_YIELD; tambien en AT y cuenta regresiva de apagado.
- Respeta ledEnabled y restaura LED por PM2.5 al entrar al loop.
- En reset que conserva modem se omite XTRA inicial para evitar hasta 120 s extra.
- Se conservan los 5 strikes y carrusel de tres datos cada 10 segundos.
- Validacion: compilacion ESP32 correcta (78% flash, 16% RAM); pruebas C++
  de orden AT/PDP/TCP, reutilizacion, servidor caido, falta de cobertura,
  recuperacion sin AT, timeout y pulso LED respetando OFF.
- TCP solo verifica el servidor consultado; sin STATUS no se verifica apagado
  fisico. Pendiente validar placa y reinicios watchdog reales.

## [V0.1.6] - 2026-10-01
### Reinicio ESP32/modem y carrusel de tres vistas cada 10 segundos
- Carrusel limitado a PM2.5, temperatura y humedad, cada 10 s.
- Navegacion manual conserva opciones; vuelve a PM2.5 tras 10 s sin seleccionar
  Empezar/Detener muestreo u Opciones. Submenus/confirmaciones permanecen abiertos.
- Icono propio con dos flechas curvas, separado del icono de reiniciar.
- Menu Reiniciar y Serial reboot comparten reinicio programado con aviso visible;
  el loop no inicia otras operaciones mientras espera los 750 ms del aviso.
- Marca de un solo uso solicita ciclo SIM7600 al reiniciar por software, tambien
  desde reinicio manual. Cuenta regresiva visible de 30 s y diagnosticos Serial.
- Se vuelve a ejecutar verificacion AT/red; se conservan 5 strikes y configuracion.
- Reinicio manual deja muestreo OFF; recuperacion automatica conserva reanudacion.
- Validacion: compilacion ESP32 correcta (77% flash, 15% RAM), icono inspeccionado
  y pruebas C++ con tiempo/Preferences simulados: 3 datos/10 s, retorno desde
  opciones, pausas, rollover, OFF persistente y marca de reinicio de un solo uso.
- Pendiente validar en placa: PWRKEY no corta VBAT y no hay STATUS para verificar.

## [V0.1.5] - 2026-10-01
### Carrusel persistente de datos y control desde Serial/menu
- Carrusel cada 5 s: PM2.5, PM1, PM10, temperatura y humedad del Plantower.
- Configuracion carouselEnabled guardada en config/carousel mediante loadConfig
  y saveConfig; OFF por defecto y con configreset.
- Serial: set carousel on/off, config display/config y ayuda help actualizada.
- Menu Configuracion: Carrusel ON/OFF, pantalla tipo RTC con BTN2 alternar y
  guardar, BTN1 salir; icono de rotacion.
- Pausa en menus, mensajes, confirmaciones, WiFi, Full y OLED inactiva.
- Navegacion manual reinicia la espera; no mantiene despierta la OLED.
- Se conservan los 5 strikes elegidos por el usuario.
- Validacion: compilacion ESP32 correcta (77% flash, 15% RAM); pruebas C++
  con Preferences/tiempo simulados para persistencia, defaults, rotacion,
  navegacion, pausas, auto-off y rollover de millis.
- Pendiente prueba visual y persistencia en hardware.

## [V0.1.4] - 2026-10-01
### Arranque paciente y recuperacion de red a los 30 minutos
- CONNECTION_MAX_STRIKES = 10 debajo de VERSION, con ventanas AT de 15 s.
- AT antes de PWRKEY y reintentos de pulso cada 3 strikes, conservando polaridad.
- Registro de red con timeout de 60 s por intento, como el original.
- Reinicio ESP32 tras 30 min continuos sin PDP; sin reinicio durante WiFi SD.
- Recuperacion solicita apagado CPOF/PWRKEY, espera 30 s y solicita encendido.
- Marca persistente de un solo uso para restaurar HTTP/SD y contadores.
- Reconexion HTTP: un intento PDP por llamada y backoff de 60 s tras fallo.
- Watchdog 180 s: TinyGSM puede bloquear 60 s en NETCLOSE y 75 s en NETOPEN.
- Validacion: compilacion ESP32 correcta (77% flash, 15% RAM) y pruebas
  C++ con modem/tiempo simulados: UART lenta, timeout, timer de 30 min,
  rollover de millis, estados de recuperacion, PWRKEY y backoff HTTP.
- Riesgos: arranque mas largo; PDP sigue bloqueante; sin STATUS/VBAT no se
  verifica apagado fisico. Pendiente validacion en hardware conocido.

## [V0.1.3] - 2026-10-01
### Perfiles de equipos y URL seleccionada por DEVICE_ID_STR
- Tabla visible en el lugar de las listas originales para los equipos 1 a 10
  y 80 a 83, conservando sus IDs del backend.
- DEVICE_ID_STR selecciona sensores, variables y extras de la URL.
- Extras SHT31/SDS198 seleccionados explicitamente por perfil.
- Constructor de URL separado del envio; valida cantidades de campos.
- IDs desconocidos o invalidos no usan el perfil de otro equipo.
- Comentarios y README explican como agregar equipos y tipos de sensores.
- Pendiente validar en hardware y contra el backend; no cambia drivers ni CSV.

## [V0.1.2] - 2026-10-01
### Arranque con strikes y funcionamiento sin red
- Espera AT limitada a 3 strikes configurables, eliminando el bucle infinito.
- Registro/PDP limitado a 3 intentos; al agotarlos pasa al modo normal.
- Sin respuesta AT se omiten GNSS, consultas del loop y apertura HTTP.
- Sin internet se omite XTRA; GNSS se inicia si hay respuesta AT.
- PDP conserva los timeouts de TinyGSM. Pendiente prueba en hardware con
  ausencia de respuesta AT, sin cobertura y con red disponible.

## [V0.1.0] - 2026-02-14
### Primera versión formal (baseline de producto)
- Se establece versión de firmware en código a **Pro V0.1.0** (`FirmwarePro.ino`).
- Ajustes finales de UI WiFi:
  - Pantalla WiFi dedicada mostrando **SSID / PASS / IP**.
  - Control por botones según estado WiFi:
    - Con WiFi activo: pantalla bloqueada (sin salida accidental).
    - Toggle ON/OFF por BTN2.
- Se repone feedback visual de arranque de módem:
  - Parpadeo de LED RGB durante `MODEM Starting...` para indicar actividad y evitar falsa percepción de bloqueo.
- Documentación ordenada en carpeta `documentacion/` con `README.md` en raíz y `LICENSE` en root del repo.

## [V0.0.35] - 2026-02-14
### WiFi SD, documentación y control de release
- Se consolidó versión de firmware a **Pro V0.0.35**.
- Se implementó flujo de **WiFi SD** con mejoras para uso desde Windows (captive portal DNS).
- Se creó documentación formal en Markdown:
  - `README.md`
  - `MANUAL_USUARIO.md`
  - `MANUAL_TECNICO.md`
  - `LICENSE` (CC BY-NC 4.0)
- Se realizó recuperación/validación de estabilidad tras pruebas (bootloop por SW reset reportado en terreno).
- **Commit con funcionamiento confirmado en equipo (booteo + flasheo exitoso):**
  - `6c66dbb` (reaplicación de cambios WiFi exclusivo)
  - Flasheado exitosamente en COM5 con verificación hash y reset OK.

## [V0.0.33] - 2026-02-14
### Notas operativas en CSV + menú Mensajes
- Se agregó nueva columna `notas` al CSV al final del header:
  - `...,pm100,notas`
- Se agregó opción **"Otros"** al submenú **Mensajes**.
- Lógica de nota one-shot:
  - Al seleccionar `Camion`, `Humo`, `Construccion` u `Otros`, se guarda esa nota en la próxima fila CSV.
  - Luego se limpia automáticamente para evitar repetición.

## [V0.0.26] - 2026-02-13
### Mejoras en UI y Lógica de Muestreo
- **Nuevo Prompt de Confirmación:** Se reemplazó el aviso simple por un cuadro de diálogo claro: "¿CONFIRMAR ACCIÓN? INICIAR/DETENER MUESTREO".
- **Lógica de Botones en Prompt:** 
  - **BTN1:** Cancela la acción y vuelve al menú.
  - **BTN2:** Confirma e inicia/detiene el proceso.
- **Muestreo Inmediato:** Al confirmar el inicio, se fuerza una ejecución inmediata de guardado en SD y envío HTTP para feedback visual instantáneo (LED/Header).
- **Depuración:** Se añadieron mensajes por puerto serial para rastrear clics de botones físicamente.

## [V0.0.25] - 2026-02-13
### Reestructuración de Navegación
- **Modo FULL en Menú:** Se eliminó el acceso por pulsación larga (Hold) y se añadió como la 5ª opción del Menú Principal.
- **Salida de Modo FULL:** Ahora se sale del modo bloqueado haciendo clic en el **BTN1 (izquierdo)**, devolviendo al usuario al menú principal.
- **Hold Desactivado:** Se deshabilitó la función de mantener presionado el botón derecho para evitar saltos accidentales de pantalla.

## [V0.0.24] - 2026-02-13
### Seguridad de Operación
- **Implementación de Full Lock:** Bloqueo de navegación de menús mientras el dispositivo está en modo de visualización de datos (Modo FULL).
- **Control de Muestreo:** Sincronización de BTN2 para alternar inicio/parada tanto en menú como en vista bloqueada.

## [V0.0.23] - 2026-02-13
### Versión Inicial Fusionada
- Integración de Backend GPSDebug con UI de Menús HIRI_PR0.
- Soporte para sensores PMS5003, SHT31, SDS198.
- Registro en SD y transmisión HTTP concurrente.

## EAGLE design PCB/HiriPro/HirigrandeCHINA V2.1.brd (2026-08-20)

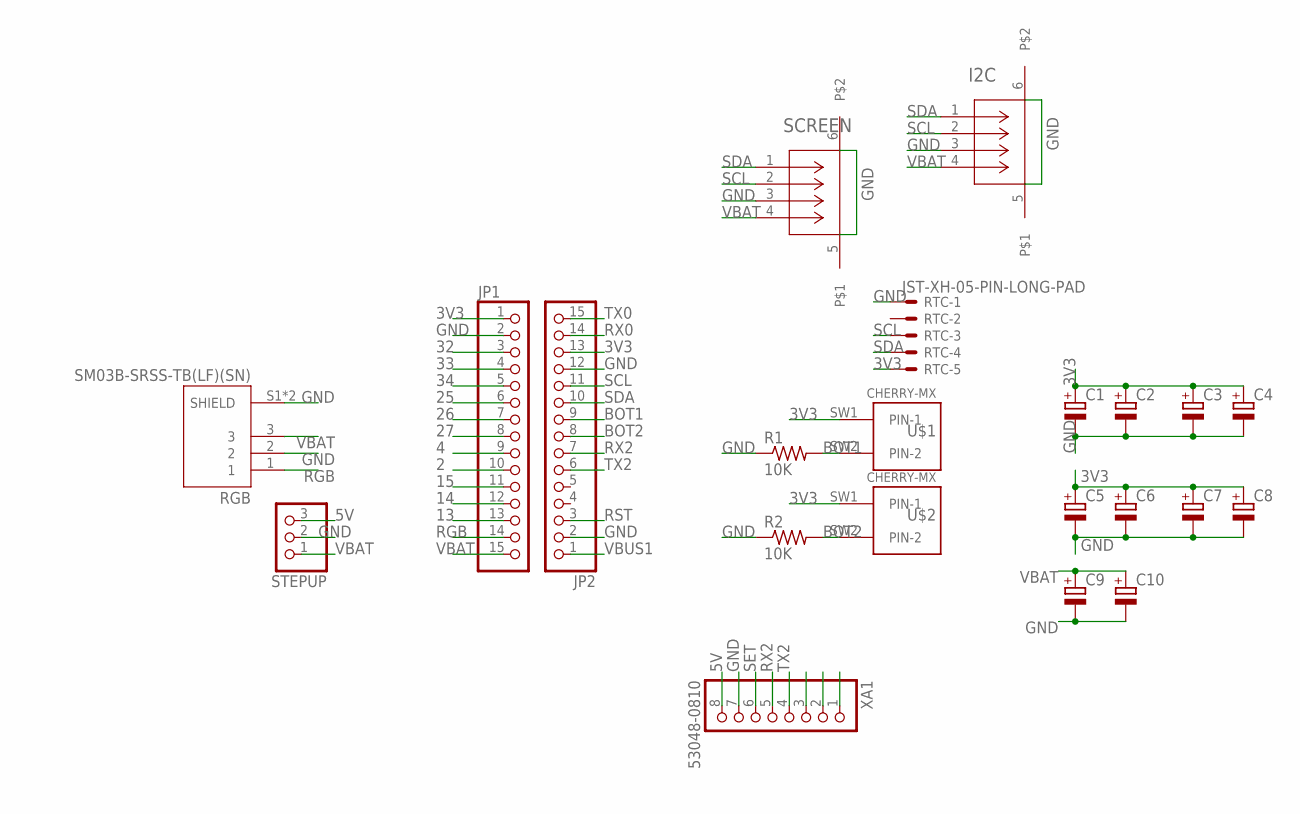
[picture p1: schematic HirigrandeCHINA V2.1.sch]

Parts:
C1, C2, C3, C4, C5, C6, C7, C8, C9, C10: CPOL-EUSMCD; SMC_D
I2C: SM04B-SRSS-TB; CONN_SM04B-SRSS-TB_JST
JP1, JP2: PINHD-1X15; 1X15
R1, R2: 10K; 0204/7
RGB: SM03B-SRSS-TB(LF)(SN); JST_SM03B-SRSS-TB(LF)(SN)
RTC: JST-XH-05-PIN-LONG-PAD; JST-XH-05-PACKAGE-LONG-PAD
SCREEN: SM04B-SRSS-TB; CONN_SM04B-SRSS-TB_JST
STEPUP: PINHD-1X3; 1X03
U$1, U$2: CHERRY-MX
XA1: 53048-0810; MOLEX_53048-0810

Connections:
2: JP1.10
3V3: C1.+, C2.+, C3.+, C4.+, C5.+, C6.+, C7.+, C8.+, JP1.1, JP2.13, RTC.5, U$1.SW1 (PIN-1), U$2.SW1 (PIN-1)
4: JP1.9
5V: STEPUP.3, XA1.8
13: JP1.13
14: JP1.12
15: JP1.11
25: JP1.6
26: JP1.7
27: JP1.8
32: JP1.3
33: JP1.4
34: JP1.5
BOT1: JP2.9, R1.2, U$1.SW2 (PIN-2)
BOT2: JP2.8, R2.2, U$2.SW2 (PIN-2)
GND: C1.-, C2.-, C3.-, C4.-, C5.-, C6.-, C7.-, C8.-, C9.-, C10.-, I2C.3, I2C.5, I2C.6, JP1.2, JP2.2, JP2.12, R1.1, R2.1, RGB.2, RGB.S1 (SHIELD), RGB.S2 (SHIELD), RTC.1, SCREEN.3, SCREEN.5, SCREEN.6, STEPUP.2, XA1.7
RGB: JP1.14, RGB.1
RST: JP2.3
RX0: JP2.14
RX2: JP2.7, XA1.5
SCL: I2C.2, JP2.11, RTC.3, SCREEN.2
SDA: I2C.1, JP2.10, RTC.4, SCREEN.1
SET: XA1.6
TX0: JP2.15
TX2: JP2.6, XA1.4
VBAT: C9.+, C10.+, I2C.4, JP1.15, RGB.3, SCREEN.4, STEPUP.1
VBUS1: JP2.1

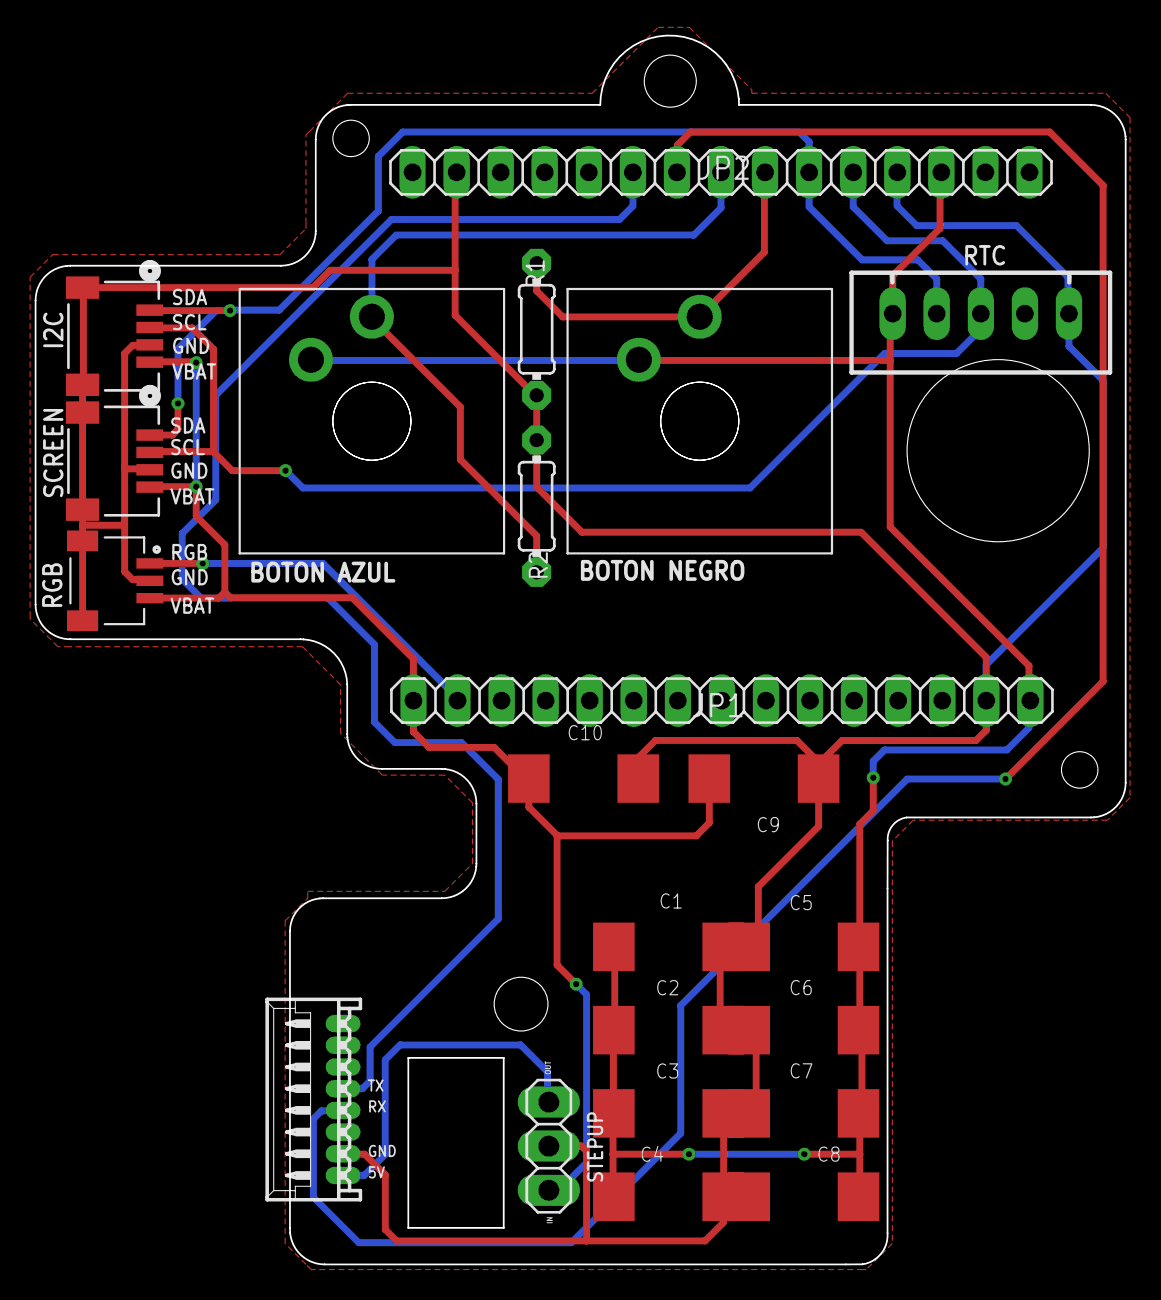
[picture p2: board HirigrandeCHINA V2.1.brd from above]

Board: 2 copper layers, 62.8 x 70.8 mm, 22 parts (0 on the bottom side), 11 nets.

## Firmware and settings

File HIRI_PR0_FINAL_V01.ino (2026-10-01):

/*
 * FirmwarePro.ino
 * Merged Firmware: GPSDebug Backend + Menu UI
 *
 * Features:
 * - GPS/GNSS (Sim7600)
 * - PMS5003 + SHT31 + SDS198 Sensors
 * - SD Card Logging
 * - HTTP Streaming
 * - OLED UI with Menus (U8g2)
 * - Navigation: OneButton (BTN1=Cycle, BTN2=Select/Hold)
 * - WiFi AP for File Management
 */

// Modem definition moved to config.h

#include "Adafruit_SHT31.h"
#include "FS.h"
#include "SD.h"
#include "SPI.h"
// #include <Adafruit_NeoPixel.h> // Moved to config.h
// #include <Arduino.h> // Included in config.h
#include <Preferences.h>
#include <RTClib.h>
#include <SoftwareSerial.h>
// #include <TinyGsmClient.h> // Moved to config.h
#include <U8g2lib.h>
#include <WebServer.h>
#include <DNSServer.h> // Added for Captive Portal
#include <WiFi.h>
#include <Wire.h>
#include <esp_task_wdt.h>

// -------------------- DEFINES & GLOBALS --------------------
#include "config.h"

// Modem modem
// #define TINY_GSM_RX_BUFFER 4096 // Moved to config.h
#define SerialAT Serial1
TinyGsm modem(SerialAT);

// --- Missing global constants/state restored for broken build ---
#define RTC_PROBE_PERIOD_MS 60000
#define RTC_SYNC_THRESHOLD 30
#define MIN_VALID_EPOCH 1672531200 // 2023-01-01

// SDS198 protocol constants
const byte HEADER = 0xAA;
const byte CMD = 0xB4;
const byte TAIL = 0xAB;

// Firmware version
String VERSION = "Pro V0.1.8";
const uint8_t CONNECTION_MAX_STRIKES = 5; // EDITAR AQUI: intentos AT y de red.
static_assert(CONNECTION_MAX_STRIKES > 0, "Debe haber al menos un strike");
// Cada strike AT permite iniciar el modem; no es una consulta instantanea.
const uint32_t MODEM_STRIKE_WINDOW_MS = 15000;
const uint8_t MODEM_PWRKEY_RETRY_EVERY = 3; // Pulso cada 3 ventanas sin AT.
const uint32_t NETWORK_ATTACH_TIMEOUT_MS = 60000; // Igual que el arranque antiguo.
const uint32_t NETWORK_REBOOT_AFTER_MS = 30UL * 60UL * 1000UL;
const uint32_t NETWORK_HEALTH_PERIOD_MS = 60000;

// Global states
bool rtcOK = false;
bool SHT31OK = false;
bool SDOK = false;
bool wifiModeActive = false;
bool hasRed = false;
bool modemReady = false; // Sin respuesta AT: operar con sensores locales.
bool offlineTracking = false;
uint32_t offlineSinceMs = 0;
uint32_t lastNetworkHealthMs = 0;
bool resumeAfterNetworkRecovery = false;
bool modemRecoveryOnBoot = false; // Habilita recuperacion si falla AT; no fuerza ciclo.
bool bootLedActive = false;
uint32_t bootLedLastMs = 0;
bool bootLedOn = false;
bool systemRestartPending = false;
uint32_t systemRestartRequestedMs = 0;
bool recoveryStreaming = false;
bool recoveryLogging = false;

// Config Instance
SystemConfig config;

// Objects
U8G2_SSD1306_128X64_NONAME_F_HW_I2C u8g2(U8G2_R0, /* reset=*/U8X8_PIN_NONE);
Adafruit_NeoPixel pixels(NUMPIXELS, NEOPIX_PIN, NEO_GRB + NEO_KHZ800);
Adafruit_SHT31 sht31 = Adafruit_SHT31();
RTC_DS3231 rtc;
Preferences prefs;
SPIClass spiSD(HSPI);
WebServer server(80); // Used in wifi.ino
DNSServer dnsServer;  // Captive Portal DNS

// PMS
SoftwareSerial pms(pms_TX, pms_RX);

// Button flags (edge + debounce)
// Button flags (edge + debounce)
volatile bool btn1ClickFlag = false;
volatile bool btn2ClickFlag = false;
volatile bool btn2HoldFlag = false;

// Internal Flags for ISR State tracking
// (Removed complex hold state tracking)

// Debounce Tracking
volatile uint32_t lastDebounceTime1 = 0;
volatile uint32_t lastDebounceTime2 = 0;
const uint32_t BTN1_DEBOUNCE_MS = 200; // Increased for Button 1 stability
const uint32_t BTN2_DEBOUNCE_MS = 200;  // Increased for Button 2 stability (was 50)

// Data Variables
uint16_t PM1 = 0, PM25 = 0, PM10 = 0;
float pmsTempC = NAN, pmsHum = NAN;
int SDS198PM100 = 0;
float tempsht31 = NAN, humsht31 = NAN;
float rtcTempC = NAN;
float batV = 0.0f;
int csq = 0;
bool networkError = false;

// GPS Data
String gpsLat = "NaN", gpsLon = "NaN";
String gpsTime = "N/A", gpsDate = "N/A";
String satellitesStr = "0", hdopStr = "N/A", gpsAlt = "N/A";
String gpsStatus = "NoFix";
String gpsSpeedKmh = "0.0";

// Internal Logic Variables
bool loggingEnabled = false;
bool streaming = false;

String csvFileName = "";
String logFilePath = "";
String failedTxPath = "";
String currentNote = "3"; // Global note for one-shot logging
// Variables moved to main for centralization
String lastSavedCSVLine = ""; // Used in sd_card.ino for OLED display
File uploadFile;              // Used in wifi.ino for file uploads

String deviceID = "/HIRIP";
// CAMBIAR SOLO ESTE ID para seleccionar el equipo y su URL de mediciones.
// Se aceptan ceros iniciales: "06" selecciona el mismo equipo que "6".
const char *DEVICE_ID_STR = "81";
String AP_SSID_STR = "";
const char *AP_PASSWORD = "12345678";
String apIpStr = "0.0.0.0";
// -------------------- Measurements API (real endpoint) --------------------
const char *API_BASE = "http://api-sensores.cmasccp.cl/insertarMedicion";
// ================= TABLA DE EQUIPOS / SENSORES API =================
// Mantener aqui los IDs asignados por el backend (no se calculan por formula).
// Orden de los 17 valores base, alineado con idsSensores e idsVariables:
//  1..5  PMS: temperatura, humedad, PM1, PM2.5, PM10
//  6..10 Modem/GPS: latitud, longitud, senal, velocidad, satelites
// 11..12 RTC: temperatura; bateria: voltaje
// 13..17 Equipo: latitud, longitud, DEVICE_ID_STR, contador, estado SD
// Extras al final: SHT31 = temperatura/humedad; SDS198 = PM100.
const char *IDS_VARIABLES = "3,6,7,8,9,11,12,15,45,46,3,4,11,12,42,43,44";
const char *IDS_VARIABLESSHT31 = "3,6,7,8,9,11,12,15,45,46,3,4,11,12,42,43,44,3,6";
const char *IDS_VARIABLES06 = "3,6,7,8,9,11,12,15,45,46,3,4,11,12,42,43,44,51";

enum ExtraSensorApi { EXTRA_NONE, EXTRA_SHT31, EXTRA_SDS198 };
struct DeviceApiProfile {
  uint16_t deviceId;
  const char *sensorIds;
  const char *variableIds;
  ExtraSensorApi extraSensor;
};

// Columnas: ID equipo | IDs sensores backend | IDs variables | sensor extra.
// NUEVO EQUIPO: copiar una fila y reemplazar ID e IDs del backend.
// No cambiar las filas existentes para agregar otro equipo.
const DeviceApiProfile DEVICE_API_PROFILES[] = {
  { 1, "401,401,401,401,401,402,402,402,402,402,403,404,405,405,405,405,405", IDS_VARIABLES, EXTRA_NONE}, // Equipo 1: 17 valores
  { 2, "406,406,406,406,406,407,407,407,407,407,408,409,410,410,410,410,410", IDS_VARIABLES, EXTRA_NONE}, // Equipo 2: 17 valores
  { 3, "415,415,415,415,415,416,416,416,416,416,417,418,419,419,419,419,419,420,420", IDS_VARIABLESSHT31, EXTRA_SHT31}, // Equipo 3: 19 valores
  { 4, "448,448,448,448,448,449,449,449,449,449,450,451,452,452,452,452,452,453,453", IDS_VARIABLESSHT31, EXTRA_SHT31}, // Equipo 4: 19 valores; nota original: no actualizado en DICTUC
  { 5, "454,454,454,454,454,455,455,455,455,455,456,457,458,458,458,458,458,459,459", IDS_VARIABLESSHT31, EXTRA_SHT31}, // Equipo 5: 19 valores
  { 6, "460,460,460,460,460,461,461,461,461,461,462,463,464,464,464,464,464,467", IDS_VARIABLES06, EXTRA_SDS198}, // Equipo 6: 18 valores
  { 7, "468,468,468,468,468,469,469,469,469,469,470,471,472,472,472,472,472", IDS_VARIABLES, EXTRA_NONE}, // Equipo 7: 17 valores
  { 8, "473,473,473,473,473,474,474,474,474,474,475,476,477,477,477,477,477", IDS_VARIABLES, EXTRA_NONE}, // Equipo 8: 17 valores
  { 9, "478,478,478,478,478,479,479,479,479,479,480,481,482,482,482,482,482,483,483", IDS_VARIABLESSHT31, EXTRA_SHT31}, // Equipo 9: 19 valores
  {10, "484,484,484,484,484,485,485,485,485,485,486,487,488,488,488,488,488,489,489", IDS_VARIABLESSHT31, EXTRA_SHT31}, // Equipo 10: 19 valores
  {80, "927,927,927,927,927,928,928,928,928,928,929,930,931,931,931,931,931,932,932", IDS_VARIABLESSHT31, EXTRA_SHT31}, // Equipo 80: 19 valores
  {81, "933,933,933,933,933,934,934,934,934,934,935,936,937,937,937,937,937,938,938", IDS_VARIABLESSHT31, EXTRA_SHT31}, // Equipo 81: 19 valores
  {82, "939,939,939,939,939,940,940,940,940,940,941,942,943,943,943,943,943,944,944", IDS_VARIABLESSHT31, EXTRA_SHT31}, // Equipo 82: 19 valores
  {83, "945,945,945,945,945,946,946,946,946,946,947,948,949,949,949,949,949,950,950", IDS_VARIABLESSHT31, EXTRA_SHT31}, // Equipo 83: 19 valores
  {84, "951,951,951,951,951,952,952,952,952,952,953,954,955,955,955,955,955,956,956", IDS_VARIABLESSHT31, EXTRA_SHT31}, // Equipo 84: 19 valores
  {85, "957,957,957,957,957,958,958,958,958,958,959,960,961,961,961,961,961,962,962", IDS_VARIABLESSHT31, EXTRA_SHT31}, // Equipo 85: 19 valores
  {86, "963,963,963,963,963,964,964,964,964,964,965,966,967,967,967,967,967,968,968", IDS_VARIABLESSHT31, EXTRA_SHT31}, // Equipo 86: 19 valores
  {87, "969,969,969,969,969,970,970,970,970,970,971,972,973,973,973,973,973,974,974", IDS_VARIABLESSHT31, EXTRA_SHT31}, // Equipo 87: 19 valores
  {88, "975,975,975,975,975,976,976,976,976,976,977,978,979,979,979,979,979,980,980", IDS_VARIABLESSHT31, EXTRA_SHT31}, // Equipo 88: 19 valores
  {89, "981,981,981,981,981,982,982,982,982,982,983,984,985,985,985,985,985,986,986", IDS_VARIABLESSHT31, EXTRA_SHT31}, // Equipo 89: 19 valores
};
// NUEVO TIPO DE SENSOR: agregar su enum, lista de variables y lectura de valores
// en buildMeasurementUrl(); inicializar/leer su hardware en setup()/loop().
// Esta tabla configura telemetria; no reemplaza los drivers de los sensores.
const DeviceApiProfile *activeApiProfile = nullptr;

String valores;
String url;

// Cuenta campos CSV simples en constantes tipo "1,2,3".
// Se usa para mantener alineados idsSensores/idsVariables/valores.
uint8_t countCsvFields(const char *csv) {
  if (csv == nullptr || csv[0] == '\0')
    return 0;

  uint8_t count = 1;
  for (const char *p = csv; *p != '\0'; ++p) {
    if (*p == ',')
      count++;
  }
  return count;
}

// APN
const char apn[] = "gigsky-02";
const char gprsUser[] = "";
const char gprsPass[] = "";

// Counters
uint32_t sendCounter = 0;
uint32_t sdSaveCounter = 0;
// Separamos guardado SD y transmisión HTTP con timers independientes.
uint32_t lastHttpSend = 0;
uint32_t lastSdSave = 0;
// Estado de actividad para UI (header U/S).
uint32_t lastHttpActivityMs = 0;
uint32_t lastSdActivityMs = 0;
bool lastHttpOk = false;
bool lastSdOk = false;
uint8_t lastDayLogged = 0;
bool wasStreamingBeforeBoot = false;

// Animation Variables
int logoXOffset = -25;
int hiriXOffset = 128;
int proYOffset = 64;
const int LOGO_FINAL_X = 4;
const int HIRI_FINAL_X = 48;
const int PRO_FINAL_X = 106;
const int HIRI_FINAL_Y = 44;
const int PRO_FINAL_Y = 52;

// Watchdog
// TinyGSM puede esperar 60 s en NETCLOSE + 75 s en NETOPEN.
// Un reset antes de que retorne gprsConnect no permite terminar el intento.
#define WDT_TIMEOUT 180
String rebootReason = "Unknown";
String networkOperator = "N/A";
String networkTech = "N/A";
String signalQuality = "0";
String registrationStatus = "N/A";

// XTRA
uint32_t lastXtraDownload = 0;
bool xtraSupported = false;
bool xtraLastOk = false;
const uint32_t XTRA_REFRESH_MS = 3UL * 24UL * 60UL * 60UL * 1000UL;

// Display State
// Display State
volatile DisplayState displayState = DISP_NORMAL;
volatile uint32_t displayStateStartTime = 0;
uint32_t lastOledActivity = 0;

// Modem Sync
uint8_t rtcModemSyncCount = 0;
uint32_t lastModemSyncAttempt = 0;
const uint32_t MODEM_SYNC_INTERVAL_MS = 600000;
const uint8_t MAX_MODEM_SYNC_COUNT = 3;
bool rtcNetSyncPending = false;
uint32_t rtcNextProbeMs = 0;

// AT Command Struct
struct AtSession {
  bool active = false;
  String expect1;
  String expect2;
  String resp;
  uint32_t deadline = 0;
} at;

// Buffer for PMS
static uint8_t pmsBuf[64];
static size_t pmsHead = 0;
static uint32_t lastPmsSeen = 0;

// Battery Averaging
const float alpha = 0.8;
float batteryVoltageAverage = 0;
static uint32_t lastBatSample = 0;
static float batSampleSum = 0;
static int batSampleCount = 0;
const int NUM_SAMPLES = 30;
const uint32_t BAT_SAMPLE_INTERVAL_MS = 5;

// Variables needed for GPS diag
uint32_t lastNmeaSeenMs = 0;
uint32_t gnssFixFirstMs = 0;
bool gnssFixReported = false;
uint8_t gsaFixType = 0;
uint8_t gsaSatsUsed = 0;
float gsaPdop = NAN, gsaHdop2 = NAN, gsaVdop = NAN;
uint16_t gsvSatsInView = 0;
float gsvSnrAvg = 0, gsvSnrMax = 0;
uint32_t gsvLastMs = 0;
float gsvSnrAcc = 0;
int gsvSnrCnt = 0;
uint32_t lastNmeaMs = 0;
uint32_t lastGgaMs = 0;
uint32_t lastFixMs = 0;
uint16_t nmeaCount1s = 0;
uint16_t nmeaRate = 0;
uint32_t nmeaRefMs = 0;
uint8_t fixQLast = 0;
bool ttffPrinted = false;
uint32_t gnssStartMs = 0;
bool haveFix = false;

// GnssDbgState moved to gps.ino

// SD Definition constants
const int SD_SCLK = 14, SD_MISO = 2, SD_MOSI = 15, SD_CS = 13;

// Extern function declarations (if needed explicitly, though linking usually
// handles it)
void loadConfig();
void applyLEDConfig();
void writeErrorLogHeader();
String generateCSVFileName();
void writeCSVHeader();
void drawAnimation(); // From animacion.ino
void startWifiApServer();
void stopWifiApServer();
void renderDisplay(); // From ui.ino
void showMessage(const char *msg);
bool saveCSVData();
void checkRebootReason();
void logError(const String &type, const String &ctx, const String &msg);
void readPMS();
bool readFrameSDS198(byte *buf);
void updatePmLed(float pm25);
void gnssBringUp();
void gnssDiagTick();
void gnssDebugPollAsync();
void gnssWatchdog();
bool atTick(bool &done, bool &ok);
bool atRun(const String &cmd, const String &expect1 = "OK",
           const String &expect2 = "ERROR", uint32_t timeout_ms = 8000);
bool sendAtSync(const String &cmd, String &resp, uint32_t timeout_ms = 4000);
bool httpGet_webhook(const String &url);
bool detectAndEnableXtra();
bool downloadXtraOnce();
void downloadXtraIfDue();
void parseNMEA(const String &line);
void saveFailedTransmission(const String &url, const String &errorType);
bool sendCurrentMeasurement();
void handleButtonLogic(); // Renamed from dispatchButtonFlags

// ISR Function Prototypes
void IRAM_ATTR isr_btn1();
void IRAM_ATTR isr_btn2();

// UI Event Handlers
extern void ui_btn1_click();
extern void ui_btn2_click();

// Oled Status Helper (used by wifi/main)
// Renderiza un estado rápido en OLED con hasta 4 líneas de texto.
// Se usa para feedback de arranque, red, módem y operaciones críticas.
void oledStatus(const String &l1, const String &l2 = "", const String &l3 = "",
                const String &l4 = "") {
  u8g2.clearBuffer();
  u8g2.setFont(u8g2_font_5x7_tf);
  u8g2.setCursor(0, 12);
  u8g2.print(l1);
  u8g2.setCursor(0, 26);
  u8g2.print(l2);
  u8g2.setCursor(0, 40);
  u8g2.print(l3);
  u8g2.setCursor(0, 54);
  u8g2.print(l4);
  u8g2.sendBuffer();
}

// AT Helper (needed in main)
// Inicia una sesión AT no bloqueante, guarda expectativas y timeout.
// La respuesta se procesa luego con atTick() para no congelar el loop.
void atBegin(const String &cmd, const String &expect1, const String &expect2,
             uint32_t timeout_ms) {
  modem.stream.print("AT");
  modem.stream.println(cmd);
  at.active = true;
  at.expect1 = expect1;
  at.expect2 = expect2;
  at.resp = "";
  at.deadline = millis() + timeout_ms;
}

// Avanza la máquina de estados AT leyendo serial y detectando fin/timeout.
// También enruta tramas NMEA entrantes al parser GNSS cuando aparecen.
bool atTick(bool &done, bool &ok) {
  bootLedTick();
  while (SerialAT.available()) {
    String line = SerialAT.readStringUntil('\n');
    line.trim();
    if (line.isEmpty())
      continue;

    if (line.charAt(0) == '$') {
      parseNMEA(line);
      continue;
    }

    if (!at.active)
      continue;
    at.resp += line;
    at.resp += "\n";
    if (at.expect1.length() && line.indexOf(at.expect1) >= 0) {
      done = true;
      ok = true;
      at.active = false;
      return true;
    }
    if (at.expect2.length() && line.indexOf(at.expect2) >= 0) {
      done = true;
      ok = (at.expect2 == "OK");
      at.active = false;
      return true;
    }
  }
  if (at.active && millis() > at.deadline) {
    done = true;
    ok = false;
    at.active = false;
    return true;
  }
  done = false;
  ok = false;
  return false;
}

// Ejecuta un comando AT de forma bloqueante hasta éxito, error o timeout.
// Es un helper práctico para setup y tareas puntuales de configuración.
bool atRun(const String &cmd, const String &expect1, const String &expect2,
           uint32_t timeout_ms) {
  atBegin(cmd, expect1, expect2, timeout_ms);
  bool done = false, ok = false;
  while (!done) {
    if (atTick(done, ok))
      break;
    delay(1);
  }
  return ok;
}

// Envía AT y devuelve la respuesta completa en un String para diagnóstico.
// Útil cuando se necesita parsear contenido (no solo OK/ERROR).
bool sendAtSync(const String &cmd, String &resp, uint32_t timeout_ms) {
  atBegin(cmd, "OK", "ERROR", timeout_ms);
  bool done = false, ok = false;
  while (!done) {
    if (atTick(done, ok))
      break;
    delay(1);
  }
  resp = at.resp;
  return ok;
}

// Consulta operador, tecnología y registro de red desde el módem.
// Actualiza variables globales usadas en UI, logs y comandos seriales.
void updateNetworkInfo() {
  String resp;
  if (sendAtSync("+COPS?", resp, 3000)) {
    int idx = resp.indexOf("+COPS:");
    if (idx >= 0) {
      int start = resp.indexOf('"', idx);
      int end = resp.indexOf('"', start + 1);
      if (start >= 0 && end > start) {
        networkOperator = resp.substring(start + 1, end);
      }
    }
  }
  if (sendAtSync("+COPS?", resp, 3000)) {
    if (resp.indexOf(",7") >= 0)
      networkTech = "LTE";
    else if (resp.indexOf(",2") >= 0)
      networkTech = "3G";
    else if (resp.indexOf(",0") >= 0)
      networkTech = "2G";
    else
      networkTech = "Unknown";
  }
  signalQuality = String(csq);
  if (sendAtSync("+CREG?", resp, 2000)) {
    if (resp.indexOf(",1") >= 0 || resp.indexOf(",5") >= 0)
      registrationStatus = "Registered";
    else if (resp.indexOf(",2") >= 0)
      registrationStatus = "Searching";
    else
      registrationStatus = "NotRegistered";
  }
}
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
void loop() {
  esp_task_wdt_reset();
  if (serviceSystemRestart()) return;

  // Button flags
  // Button Logic (State Check & Dispatch)
  handleButtonLogic();
  if (serviceSystemRestart()) return;

  if (wifiModeActive) {
    // No reiniciar durante gestion de archivos; dar 30 min al salir de WiFi.
    if (offlineTracking) offlineSinceMs = millis();
    // Modo WiFi Exclusivo:
    // 1. Procesa DNS (Portal Cautivo)
    // 2. Procesa WebServer
    // 3. Mantiene refresco mínimo de pantalla (para no congelar UI)
    // 4. Mantiene lectura mínima de GPS si hay FIX (para no perderlo/saturar buffer), pero sin logica pesada.
    
    dnsServer.processNextRequest();
    server.handleClient();
    
    // Mantener GPS vivo (vaciar buffer) si ya teníamos FIX, para no perderlo al salir.
    // No procesamos la data completa para ahorrar CPU, solo lectura básica si es necesario 
    // o dejamos que el buffer maneje lo suyo. 
    // En este caso, simplemente NO lo apagamos. El módulo sigue encendido.
    // Si queremos mantener el buffer limpio:
    if (haveFix) {
       // Opcional: leer y descartar o procesar mínimo. 
       // Por ahora, confiamos en que el módulo sigue con energía.
       // Solo llamamos al watchdog del GNSS para que no crea que se colgó si implementamos timeout.
       gnssWatchdog(); 
    }

    static uint32_t lastWifiDisp = 0;
    if (millis() - lastWifiDisp > 500) {
       lastWifiDisp = millis();
       renderDisplay();
    }
    return; 
  }

  networkRecoveryTick();

  // Sensors & GNSS
  if (modemReady) {
    gnssWatchdog();
    gnssDiagTick();
    gnssDebugPollAsync();
  }

  // RTC temperature refresh
  static uint32_t lastRtcTempMs = 0;
  if (rtcOK && (millis() - lastRtcTempMs >= 1000)) {
    lastRtcTempMs = millis();
    rtcTempC = rtc.getTemperature();
  }

  // First Loop Logic
  if (FirstLoop) {
    if (modemReady) {
      csq = modem.getSignalQuality();
      updateNetworkInfo();
    }
    FirstLoop = false;
  }

  // PMS & SDS
  readPMS();
  // Mantener RGB actualizado con PM2.5 aun cuando no haya transmisión HTTP.
  static uint32_t lastLedUpdateMs = 0;
  if (millis() - lastLedUpdateMs >= 300) {
    lastLedUpdateMs = millis();
    updatePmLed((float)PM25);
  }
  byte frame[10];
  if (readFrameSDS198(frame)) {
    SDS198PM100 = (uint16_t)((frame[5] << 8) | frame[4]);
    Serial.print("PM100: ");
    Serial.println(SDS198PM100);
  }

  // AT Tick
  static uint32_t lastAtTick = 0;
  if (millis() - lastAtTick >= 50) {
    lastAtTick = millis();
    bool d, o;
    (void)atTick(d, o);
  }

  // Battery Sampling
  if (millis() - lastBatSample >= BAT_SAMPLE_INTERVAL_MS) {
    lastBatSample = millis();
    batSampleSum += analogRead(BAT_PIN);
    batSampleCount++;
    if (batSampleCount >= NUM_SAMPLES) {
      float rawV = (batSampleSum / NUM_SAMPLES / 4095.0f) * 3.3f * 2.0f * 1.15f;
      if (batteryVoltageAverage == 0)
        batteryVoltageAverage = rawV;
      batteryVoltageAverage =
          (alpha * rawV) + ((1.0 - alpha) * batteryVoltageAverage);
      batV = batteryVoltageAverage;
      batSampleSum = 0;
      batSampleCount = 0;
    }
  }

  // Display Update
  static uint32_t lastDisplayUpdate = 0;
  if (millis() - lastDisplayUpdate > 60) {
    lastDisplayUpdate = millis();
    renderDisplay();
  }

  // Auto Off
  if (config.oledAutoOff &&
      (millis() - lastOledActivity > config.oledTimeout)) {
    u8g2.setPowerSave(1);
  }

  // Guardado SD (separado de transmisión HTTP)
  // Nota: por diseño de esta etapa, loggingEnabled inicia en false.
  if (loggingEnabled && (millis() - lastSdSave >= config.sdSavePeriod)) {
    lastSdSave = millis();
    bool sdSaved = saveCSVData();
    lastSdActivityMs = millis();
    lastSdOk = sdSaved;
    // Sin pantalla emergente de "guardado": se usan indicadores del header/RGB.
  }

  // Transmisión HTTP (separada de guardado SD)
  if (streaming && (millis() - lastHttpSend >= config.httpSendPeriod)) {
    lastHttpSend = millis();
    bool txOk = sendCurrentMeasurement();
    lastHttpActivityMs = millis();
    lastHttpOk = txOk;
  }

  // Serial Commands
  processSerialCommand();
}

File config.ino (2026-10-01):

// -------------------- Configuration System --------------------
// Sistema de configuración persistente en flash (Preferences)
// Configuración accesible por comandos seriales
// NOTA: struct SystemConfig y variable config están declaradas en el archivo
// principal

void resetCarouselTimer();

// -------------------- Load Configuration --------------------
void loadConfig() {
  prefs.begin("config", false);

  // SD
  config.sdAutoMount = prefs.getBool("sdAuto", false);
  config.sdSavePeriod = prefs.getUInt("sdSavePer", 3000);

  // HTTP
  config.httpSendPeriod = prefs.getUInt("httpPer", 3000);
  config.httpTimeout = prefs.getUShort("httpTO", 15);

  // Display
  config.carouselEnabled = prefs.getBool("carousel", false);
  config.oledAutoOff = prefs.getBool("oledOff", false);
  config.oledTimeout = prefs.getUInt("oledTO", 120000);

  // Power
  config.ledEnabled = prefs.getBool("ledEn", true);
  config.ledBrightness = prefs.getUChar("ledBr", 50);

  // Autostart
  config.autostart = prefs.getBool("autoStart", false);
  config.autostartWaitGps = prefs.getBool("autoGPS", false);
  config.autostartGpsTimeout = prefs.getUShort("autoGPSTO", 600);

  // GNSS Mode
  config.gnssMode = prefs.getUChar("gnssMode", 15);

  prefs.end();

  Serial.println("[CONFIG] Loaded from flash");
  Serial.printf("[CONFIG] SD auto-mount: %s, save period: %lums\n",
                config.sdAutoMount ? "ON" : "OFF", config.sdSavePeriod);
  Serial.printf("[CONFIG] HTTP send period: %lums, timeout: %us\n",
                config.httpSendPeriod, config.httpTimeout);
  Serial.printf("[CONFIG] Carousel: %s, interval: 10s\n",
                config.carouselEnabled ? "ON" : "OFF");
  Serial.printf("[CONFIG] OLED auto-off: %s, timeout: %lums\n",
                config.oledAutoOff ? "ON" : "OFF", config.oledTimeout);
  Serial.printf("[CONFIG] LED enabled: %s, brightness: %u%%\n",
                config.ledEnabled ? "YES" : "NO", config.ledBrightness);
  Serial.printf("[CONFIG] Autostart: %s, wait GPS: %s, GPS timeout: %us\n",
                config.autostart ? "YES" : "NO",
                config.autostartWaitGps ? "YES" : "NO",
                config.autostartGpsTimeout);
  Serial.printf("[CONFIG] GNSS mode: %u\n", config.gnssMode);
}

// -------------------- Save Configuration --------------------
void saveConfig() {
  prefs.begin("config", false);

  // SD
  prefs.putBool("sdAuto", config.sdAutoMount);
  prefs.putUInt("sdSavePer", config.sdSavePeriod);

  // HTTP
  prefs.putUInt("httpPer", config.httpSendPeriod);
  prefs.putUShort("httpTO", config.httpTimeout);

  // Display
  prefs.putBool("carousel", config.carouselEnabled);
  prefs.putBool("oledOff", config.oledAutoOff);
  prefs.putUInt("oledTO", config.oledTimeout);

  // Power
  prefs.putBool("ledEn", config.ledEnabled);
  prefs.putUChar("ledBr", config.ledBrightness);

  // Autostart
  prefs.putBool("autoStart", config.autostart);
  prefs.putBool("autoGPS", config.autostartWaitGps);
  prefs.putUShort("autoGPSTO", config.autostartGpsTimeout);

  // GNSS Mode
  prefs.putUChar("gnssMode", config.gnssMode);

  prefs.end();

  Serial.println("[CONFIG] Saved to flash");
}

// Misma persistencia para menu y Serial; efecto inmediato, sin reiniciar.
void setCarouselEnabled(bool enabled) {
  if (config.carouselEnabled != enabled) {
    config.carouselEnabled = enabled;
    saveConfig();
  }
  resetCarouselTimer();
  Serial.printf("[CONFIG] Carousel: %s (saved, interval: 10s)\n",
                config.carouselEnabled ? "ON" : "OFF");
}

// -------------------- Reset to Defaults --------------------
void configSetDefaults() {
  config.sdAutoMount = false; // NO montar en boot
  config.sdSavePeriod = 3000; // 3 segundos

  config.httpSendPeriod = 3000; // 3 segundos
  config.httpTimeout = 15;      // 15 segundos

  config.carouselEnabled = false; // Carrusel desactivado por defecto
  resetCarouselTimer();
  config.oledAutoOff = false;  // Siempre encendida
  config.oledTimeout = 120000; // 2 minutos

  config.ledEnabled = true;  // LED habilitado
  config.ledBrightness = 50; // 50% brillo

  config.autostart = false;         // NO autostart
  config.autostartWaitGps = false;  // NO esperar GPS
  config.autostartGpsTimeout = 600; // 10 minutos (default)

  config.gnssMode = 15; // Todas las constelaciones (default)

  Serial.println("[CONFIG] Reset to defaults");
}
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

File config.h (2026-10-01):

#ifndef CONFIG_H
#define CONFIG_H

#include <Arduino.h>

// Modem definition must be before include
#define TINY_GSM_MODEM_SIM7600
#define TINY_GSM_RX_BUFFER 4096

// Modem Pins (SIM7600)
#define MODEM_TX 27
#define MODEM_RX 26
#define MODEM_PWRKEY 4
#define MODEM_DTR 32
#define MODEM_FLIGHT 25

// PMS5003 Pins (SoftwareSerial)
#define pms_RX 18
#define pms_TX 5

// Battery / Power
#define BAT_PIN 35
#define POWER_PIN 33
#define NEOPIX_PIN 12
#define NUMPIXELS 1
#define BUTTON_PIN_1 19
#define BUTTON_PIN_2 23

#include <Adafruit_NeoPixel.h>
#include <Arduino.h>
// TinyGSM ofrece este hook en sus esperas: mantener pulso de arranque sin tarea
// extra y sin tocar la biblioteca. En operacion normal bootLedTick no hace nada.
void bootLedTick();
#define TINY_GSM_YIELD() do { bootLedTick(); delay(0); } while (0)
#include <TinyGsmClient.h>

// -------------------- Configuration System --------------------
struct SystemConfig {
  // SD Card
  bool sdAutoMount;      // Montar SD en boot (default: false)
  uint32_t sdSavePeriod; // Período guardado SD en ms (default: 3000)

  // HTTP Transmission
  uint32_t httpSendPeriod; // Período transmisión en ms (default: 3000)
  uint16_t httpTimeout;    // Timeout HTTP en segundos (default: 15)

  // Display OLED
  bool carouselEnabled; // Carrusel persistente cada 10 s (default: false)
  bool oledAutoOff;     // Apagar OLED automáticamente (default: false)
  uint32_t oledTimeout; // Timeout en ms (default: 120000 = 2min)

  // Power Management
  bool ledEnabled;       // NeoPixel habilitado (default: true)
  uint8_t ledBrightness; // Brillo LED: 10, 25, 50, 100 (default: 50%)

  // Autostart
  bool autostart; // Iniciar streaming/logging al encender (default: false)
  bool autostartWaitGps; // Esperar GPS fix antes de iniciar (default: false)
  uint16_t
      autostartGpsTimeout; // Timeout GPS en segundos (default: 600 = 10min)

  // GNSS Mode
  uint8_t gnssMode; // Modo GNSS: 1=GPS, 3=GPS+GLO, 5=GPS+BDS, 7=GPS+GLO+BDS,
                    // 15=ALL (default: 15)
};

// -------------------- Display State Machine --------------------
enum DisplayState {
  DISP_NORMAL,
  DISP_SD_SAVED,
  DISP_MESSAGE,
  DISP_PROMPT,
  DISP_NETWORK,
  DISP_RTC,
  DISP_STORAGE,
  DISP_GPS,
  DISP_WIFI,
  DISP_CAROUSEL
};
#define DISP_MSG_DURATION_MS 1500

#endif

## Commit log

2026-08-18 Add independent component test for HIRI
    - Implement u8x8 string handling functions in u8x8_string.c
    - Add u16 and u8 to ASCII conversion functions in u8x8_u16toa.c and u8x8_u8toa.c
    - Create test_componentes sketch to validate OLED, RTC, NeoPixel, buttons, and battery voltage
    - Include README.md for usage instructions and component descriptions
2026-08-20 Add README.md for HIRI Pro PCB design documentation
    - Introduced detailed documentation for the HIRI Pro carrier board.
    - Included design files, hardware blocks, pinout, and firmware integration.
    - Highlighted pending issues and recommended validation procedures.
    - Emphasized the need for electrical review and compatibility checks before manufacturing.
    [HirigrandeCHINA V2.1.brd, HirigrandeCHINA V2.1.sch]
2026-08-20 Add Adafruit SHT4x Library and Unified Sensor Driver
    - Created library.properties for Adafruit SHT4x Library with metadata.
    - Added license file for Adafruit SHT4x Library.
    - Implemented Adafruit_Sensor class with printSensorDetails method in Adafruit Unified Sensor library.
    - Defined sensor types and structures in Adafruit_Sensor.h for unified sensor data handling.
    - Added LICENSE.txt for Adafruit Unified Sensor library under Apache License 2.0.
    - Created README.md for Adafruit Unified Sensor library detailing usage and examples.
    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
2026-10-01 feat: Implement persistent carousel feature for PM2.5, temperature, and humidity
    - Added configuration option for carousel in SystemConfig and updated load/save functions.
    - Introduced carousel functionality in UI, allowing rotation every 10 seconds.
    - Updated serial commands to enable/disable carousel and reflect changes in configuration.
    - Enhanced display logic to support carousel state and navigation.
    - Documented carousel feature in user and technical manuals.
